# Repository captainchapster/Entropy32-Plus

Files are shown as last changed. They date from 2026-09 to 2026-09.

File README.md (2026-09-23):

# Entropy32 Plus

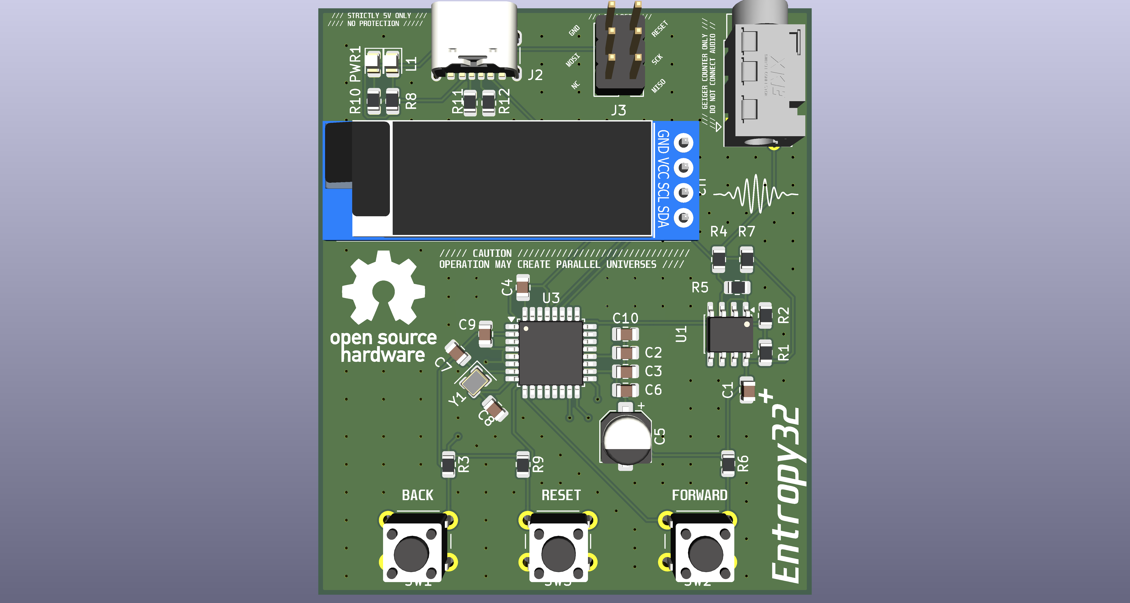
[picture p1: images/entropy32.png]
Assembled PCB


**Entropy32** (aka *The Universe Bifurcator*) is a dedicated Bitcoin seed phrase generator that uses radioactive decay as its entropy source. It's completely open source and designed to be simple, auditable, and buildable by anyone with readily available components.

## Why radioactive decay?

Pseudo-random number generators are deterministic — given the same seed, they always produce the same output. True randomness for something as consequential as a Bitcoin wallet's seed phrase should come from a physical process nobody can predict or manipulate. Radioactive decay is quantum-mechanically random: the timing of individual decay events is fundamentally unpredictable, making it an ideal entropy source for generating cryptographic secrets.

## How it works

1. A Geiger counter detects decay events from a radioactive source (or background) and outputs a pulse via a 3.5mm audio jack.
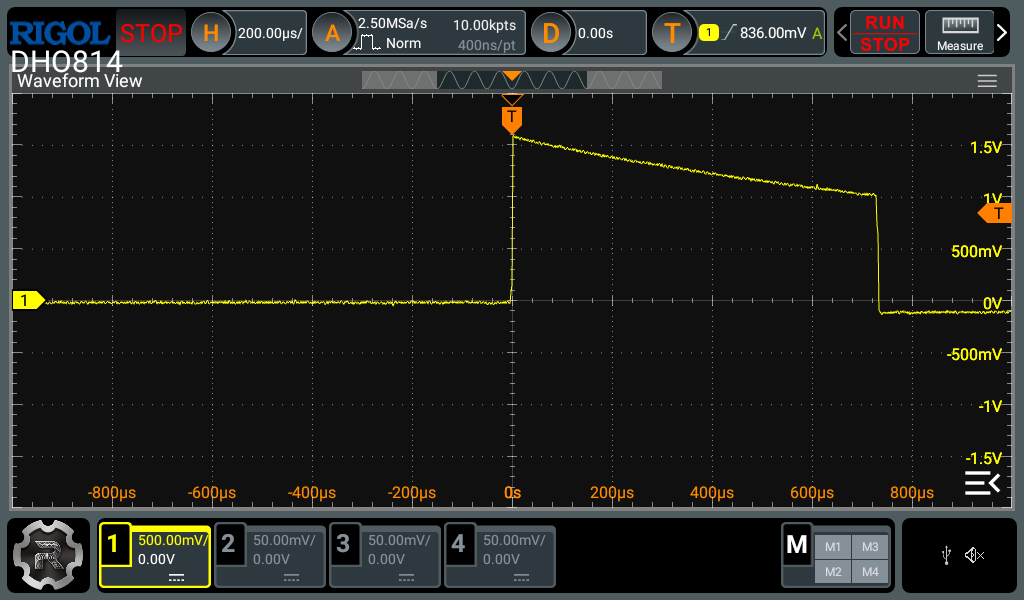
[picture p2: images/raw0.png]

2. An LM393 comparator IC then takes the 0-1.5V pulse and compares it to a bias of ~0.5V via a voltage divider such that if V>0.5V we get HIGH else LOW.
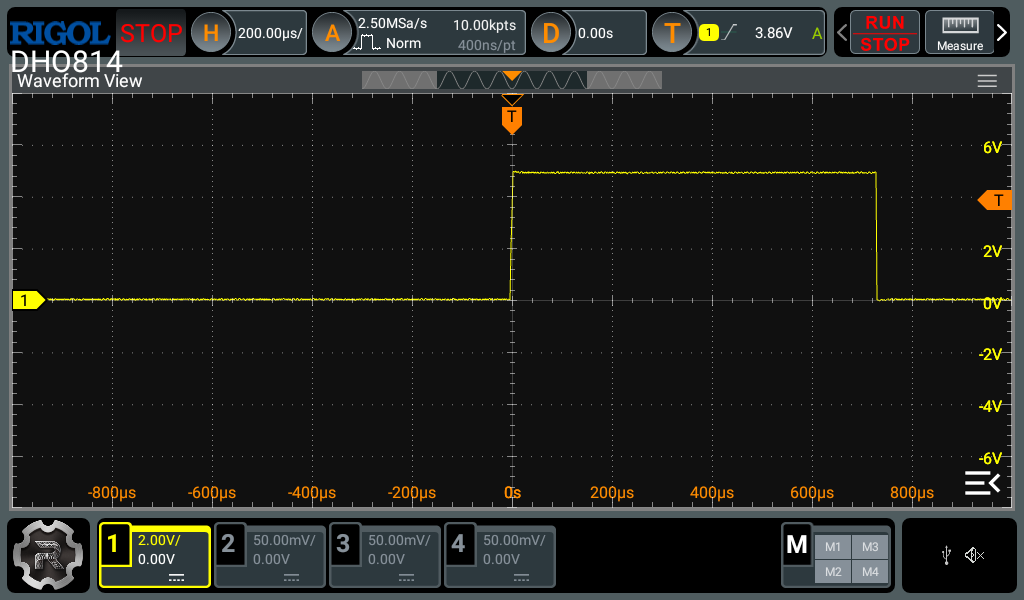
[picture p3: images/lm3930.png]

3. The timing between events is captured and compared in non-overlapping pairs (each inter-arrival time feeds exactly one comparison, so adjacent output bits never share an input interval). Each resulting bit passes two continuous NIST SP 800-90B health tests (Repetition Count Test and Adaptive Proportion Test) before it's fed through SHA-256 conditioning to whiten the raw entropy and remove any bias — if either test trips, the device halts rather than generating a seed from a degraded source.
4. The conditioned entropy is mapped to words from the standard BIP39 English wordlist.
5. A simple button-driven, state-machine UI walks you through generating and displaying your seed phrase — entirely offline, with no wireless connectivity, no persistent storage of the seed, and no software dependencies beyond the device itself.

## How long does it take to generate a seed?

The firmware always fills a 512-bit raw pool before conditioning — that's true whether you pick a 12-word or 24-word phrase, since the seed length only changes how many of the whitened bits get used afterward, not how much raw entropy gets collected. Because of the non-overlapping interval pairing described above, each output bit costs two Geiger pulses, so at a steady count rate the pool fills in roughly:

```
minutes ≈ 1024 / CPM
```

The device's collection screen shows live CPM and a running ETA using this same math, so you don't need to do it by hand. Actual CPM depends heavily on your specific tube, source activity, distance, and shielding — treat the table below as a rough guide, not a spec, and follow appropriate safety/legal practices for any check source you use:

| Source | Typical CPM | Time to fill the pool |
|---|---|---|
| Ambient background | ~15–25 CPM | ~40–70 min |
| Uranium glass ("vaseline glass") | ~50–100 CPM | ~10–20 min |
| Thoriated tungsten welding rod (2% ThO₂) | ~100–200 CPM | ~5–10 min |
| Am-241 foil (smoke detector ionization chamber) | ~300–800 CPM | ~1.3–3.5 min |
| Low-activity calibration/check source | ~1,000–3,000 CPM | ~20 sec–1 min |
| High-activity check source (close contact) | ~5,000–10,000+ CPM | ~6–12 sec |

## Hardware

- Custom PCB built around an [ATmega328P microcontroller](https://ww1.microchip.com/downloads/en/DeviceDoc/Atmel-7810-Automotive-Microcontrollers-ATmega328P_Datasheet.pdf), designed in [KiCad](https://www.kicad.org/)
- Geiger counter module as the entropy source (currently designed to take the 3.5mm output of the [GQ Electronics GMC-320S](https://www.gqelectronicsllc.com/comersus/store/comersus_viewItem.asp?idProduct=5787))
- [LM393 comparator IC](https://www.ti.com/product/LM393)
- Push-button interface for on-device operation
- Serveral common passives i.e. resistors, capacitors, and LEDs
- 16MHZ crystal oscillator
- 0.91" OLED display with I2C adaptor
- PJ320E 3.5mm audio jack
- USB-C receptacle 6 pin
- header pins

<p align="center">
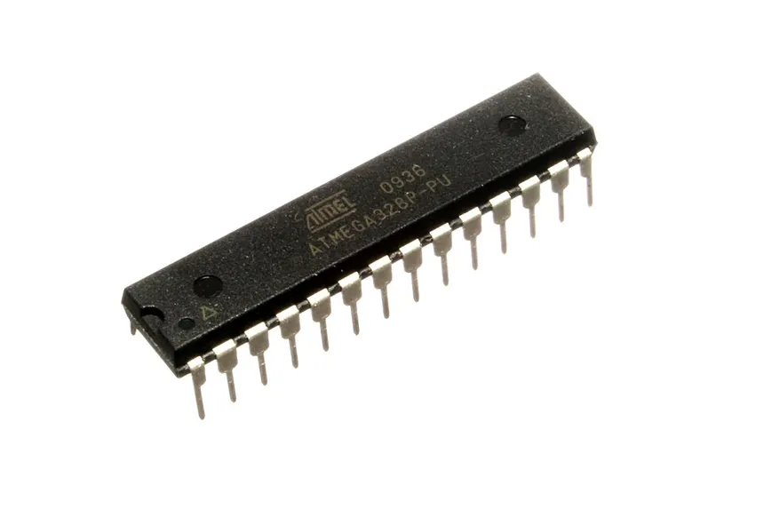
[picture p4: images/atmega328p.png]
ATmega328P
  
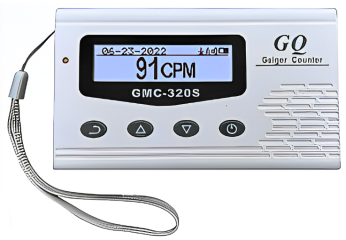
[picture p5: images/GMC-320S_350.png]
GMC-320S Geiger counter
  
</p>

## 3D printed case

I have included a custom designed basic case which you can 3d print to protect your device. The design works by allowing the board to slide on tracks into the case, once inserted all the way, a small prong prevents the board from sliding back out. If you plan to use this case be sure to hold the board down while unplugging the USB and/or the 3.5mm audio cable as this would otherwise put excessive strain on the prong to the point it may break off and fail. 

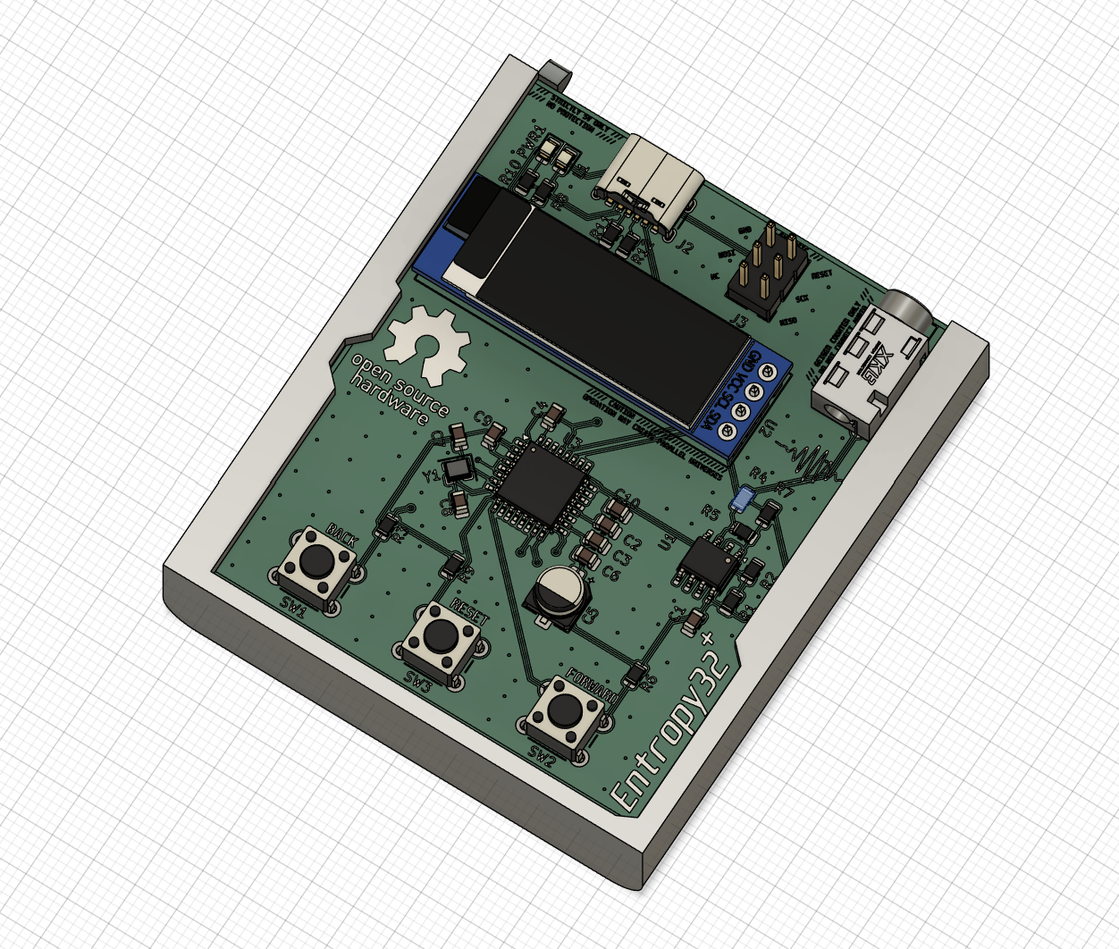
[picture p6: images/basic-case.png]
Basic Case


## Repository contents

| File | Purpose |
|---|---|
| `entropy32_plus.ino` | Main firmware — state machine, entropy capture, and UI logic |
| `sha256.h` / `sha256.cpp` | SHA-256 implementation used to condition raw entropy |
| `bip39_wordlist.h` | BIP39 English wordlist, compiled into firmware |
| `button.h` | Button input handling |
| `logo_bitmap.h` | Boot splash bitmap, compiled into firmware |
| `tools/english.txt` | Source BIP39 wordlist |
| `tools/generate_wordlist.py` | Script to regenerate `bip39_wordlist.h` from `english.txt` |
| `tools/generate_logo_bitmap.py` | Script to regenerate `logo_bitmap.h` from a rendered image |
| `KiCad/...` | Schematics, PCB and other files |
| `KiCad/production/...` | Fabrication data: bom, zipped fab files, and positions etc |
| `enclosures/...` | 3D print files for cases & enclosures |

## Building it yourself

Entropy32 schematic

The Arduino sketch (`entropy32_plus.ino`) and its accompanying `.h`/`.cpp` files must remain in the same top-level folder for the Arduino IDE to compile correctly — it doesn't recurse into subfolders for sketch code. Open `entropy32_plus.ino` in the Arduino IDE, verify your board settings for the ATmega328P, and flash as normal.

Use the KiCad files to tailor the board to your liking before fabrication or use the premade production files to order your board and/or pick and place from your preferred fabrication plant i.e. JLCPCB or PCB Way etc.

### Programming a bare ATmega328P

A freshly fabricated board has a blank ATmega328P — there's no bootloader on it and no USB-to-serial chip to flash it through, so the usual "select a port and hit upload" Arduino flow doesn't apply until it's been programmed once via the ICSP header exposed on the board.

1. **Wire up an ISP programmer.** Either a second Arduino running the `ArduinoISP` example sketch, or a dedicated programmer such as a USBasp, connected to the ICSP header. If using a USBasp, make sure it's set to 5V logic to match this board.
2. **Burn the bootloader.** In the Arduino IDE, select **Arduino Uno** or **Arduino Nano** as the board type (either is a stand-in for a bare ATmega328P at this stage), select your ISP programmer under Tools → Programmer, and run **Tools → Burn Bootloader**. This also sets the fuses for running off the board's 16MHz external crystal rather than the internal oscillator.
3. **Flash the firmware.** With the bootloader in place and the board running at 16MHz external clock, open `entropy32_plus.ino` and upload it via **Sketch → Upload Using Programmer** (still through the same ISP connection — the board has no onboard USB-serial chip for a normal serial upload).

## Flash footprint

Geiger pulse capture, the SP 800-90B runtime health tests, SHA-256 conditioning, the full BIP39 wordlist, the OLED driver, and the entire menu/boot UI all fit on the ATmega328P's 32KB of flash — with 486 bytes to spare:

```
Sketch uses 30234 bytes (98%) of program storage space. Maximum is 30720 bytes.
Global variables use 1061 bytes (51%) of dynamic memory, leaving 987 bytes for local variables. Maximum is 2048 bytes.
```

Breakdown of where it all goes, pulled from the compiled `.elf` with `avr-size`/`avr-nm`:

| Symbol | Bytes | What it is |
|---|---|---|
| `BIP39_WORDLIST_BLOB` | 13,117 | The official 2048-word BIP39 English wordlist |
| `main` (loop + inlined UI code) | 3,062 | State machine, screen drawing, menu logic |
| `SHA256::transform` | 2,278 | The SHA-256 compression function |
| `vfprintf` | 948 | Pulled in by `snprintf`, used for CPM/ETA/progress formatting |
| `u8x8_font_5x7_r` | 764 | Built-in OLED font glyph table |
| U8x8 / TwoWire internals | ~1,100 | I2C + SSD1306 driver plumbing |
| `LOGO_BITMAP` | 384 | Boot splash bitmap |
| `K` (SHA-256 round constants) | 256 | Fixed SHA-256 round constants |

The wordlist alone is 43% of the chip. Adafruit_GFX + Adafruit_SSD1306 don't fit alongside it — see the note in `entropy32_plus.ino` — which is why the firmware talks to the display through U8x8's text-only mode instead.

## Validation

The firmware runs the two minimal continuous health tests NIST SP 800-90B requires of a noise source at runtime — a Repetition Count Test and an Adaptive Proportion Test (see `runHealthChecks()` in `entropy32_plus.ino`) — which will halt the device rather than generate a seed if the raw source looks stuck or degraded. Runtime health tests are not the same as validating the source's entropy.

### Pilot entropy assessment

A 10-hour capture was logged with [Entropy32 Recorder](https://github.com/captainchapster/Entropy32-Recorder). The recorder is a separate board that timestamps the same post-LM393 D2 rising edges the firmware reads. It captured 10,000 edges (~17 CPM average) with zero buffer overruns or transport drops. The intervals were put through the firmware's exact bit derivation from this repository at `311c859`: 200 µs minimum interval, non-overlapping pairs and ties discarded. That produced 4,999 comparison bits (2,543 zeros, 2,456 ones). Those bits were assessed with NIST's [`ea_non_iid`](https://github.com/usnistgov/SP800-90B_EntropyAssessment) (v1.1.8):

| Estimator | Min-entropy (bits per bit) |
|---|---|
| Most Common Value | 0.924 |
| Collision | **0.738** |
| Markov | 0.956 |
| t-Tuple | 0.876 |
| LRS | 0.888 |
| MultiMCW prediction | 0.970 |
| Lag prediction | 0.915 |
| MultiMMC prediction | 0.919 |
| LZ78Y prediction | 0.922 |
| Compression | not run (too few samples) |

The assessed min-entropy is the lowest of these: **H ≈ 0.738 bits per comparison bit**, set by the collision estimator. At that rate, the 512-bit raw pool holds about 378 bits of min-entropy before SHA-256 conditioning. That is above the 256 bits a 24-word phrase needs.

Treat this as a pilot, not a validation:

- **4,999 samples is far short of the 1,000,000 the NIST tool is designed for.** The estimators use 99% upper confidence bounds, and those bounds are wide at this size, so the results are pessimistic. For example, the observed 50.9% / 49.1% split is within about 1.2 standard deviations of a fair coin. A full-length capture is still needed.
- It covers one device, one Geiger tube and one environment, and the source and setup details were not recorded. It says nothing about other builds.
- It is an entropy assessment, not NIST certification or formal validation.

The raw edges, derived bits, full tool output and SHA-256 checksums are all published in the [evidence directory](https://github.com/captainchapster/Entropy32-Recorder/tree/1d47487bc94c2b7c9baa2feec54d4443b60ba87c/entropy32_sp80090b_2026-09-22a), so the result can be reproduced end to end.

Please verify the entropy source you intend to use; otherwise, understand that you are using the device at your own risk.

## Disclaimer

This is a hobbyist/educational project. If you use it to generate a real Bitcoin seed phrase, understand the risks: verify the entropy quality yourself, review the code, and never trust a seed-generating device (this one included) with significant funds without independent auditing.

## Licenses

- For firmware/software, see [`MIT LICENSE`](./LICENSE).
- For hardware, see [`CERN-OHL-S v2 LICENSE`](./LICENSE-HARDWARE).

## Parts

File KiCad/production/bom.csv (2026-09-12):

Designator | Footprint | Quantity | Value | LCSC Part #
C1 | 0805 | 1 | 0.1uF
C10, C2, C9 | 0805 | 3 | 100nF
C3, C6 | 0805 | 2 | 1uF
C4 | 0805 | 1 | 100pF
C5 | CP_Elec_5x3 | 1 | 4.7uF
C7, C8 | 0805 | 2 | 10pF
J1 | Jack_3.5mm_PJ320E_Horizontal | 1 | AudioJack2
J2 | USB_C_Receptacle_GCT_USB4125-xx-x_6P_TopMnt_Horizontal | 1 | USB_C_Receptacle_PowerOnly_6P
J3 | PinHeader_2x03_P2.54mm_Vertical | 1 | ICSP
L1 | 0805 | 1 | Yellow
PWR1 | 0805 | 1 | Green
R1, R3, R6, R7, R9 | 0805 | 5 | 10k
R10 | 0805 | 1 | 2.2k
R11, R12 | 0805 | 2 | 5K1
R2, R4, R8 | 0805 | 3 | 1k
R5 | 0805 | 1 | 100k
SW1 | SW_PUSH_6mm | 1 | REV
SW2 | SW_PUSH_6mm | 1 | FWD
SW3 | SW_PUSH_6mm | 1 | RESET
U1 | SOIC-8_3.9x4.9mm_P1.27mm | 1 | LM393
U2 | ER_OLEDM0.91_1x-I2C | 1 | ER_OLEDM0.91_1x-I2C
U3 | TQFP-32_7x7mm_P0.8mm | 1 | ATmega328P-A
Y1 | Crystal_SMD_2520-4Pin_2.5x2.0mm | 1 | 16MHz

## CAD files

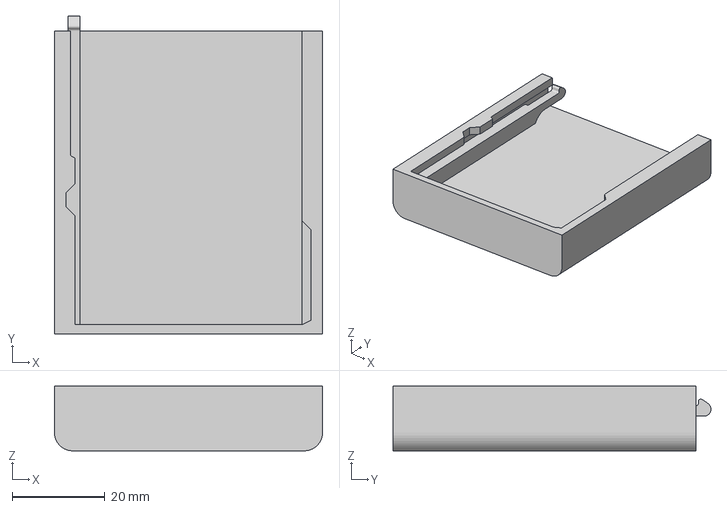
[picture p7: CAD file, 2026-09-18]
enclosures/Basic-case.3mf
58.0 x 68.7 x 14.0 mm

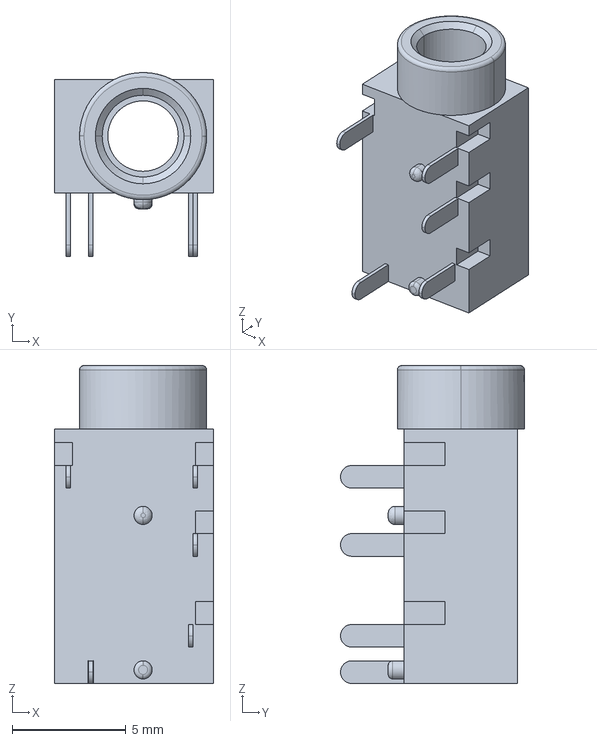
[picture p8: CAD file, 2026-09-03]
KiCad/3d_models/189198069-19-pj-320e/pj-320e.stp
7.00 x 8.10 x 14.0 mm

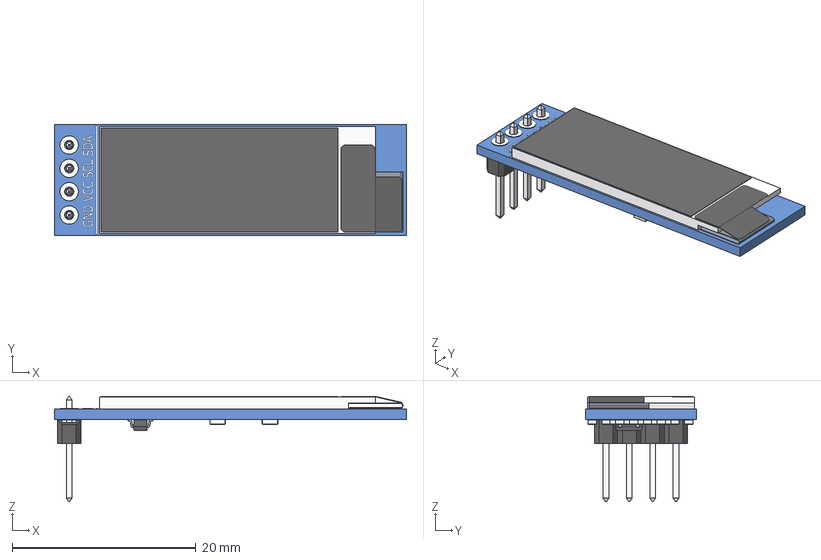
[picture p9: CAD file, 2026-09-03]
KiCad/3d_models/oled-0-91-128x32-1.snapshot.1/OLED_0.91_128x32.stp
38.3 x 12.1 x 11.5 mm
OLED_0.91_128x32
Pin Header 4 x 1 TH 2.54mm Pitch
RESC-0603 x 13
2SD0601A

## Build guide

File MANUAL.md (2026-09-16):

# Entropy32 Plus — User Manual

*"The Universe Bifurcator"*

<!-- IMAGE: hero shot — assembled device in its case, screen lit up on the
     collecting screen, Geiger counter cabled in beside it. This is the
     manual's cover image; make it the nicest photo you have. -->
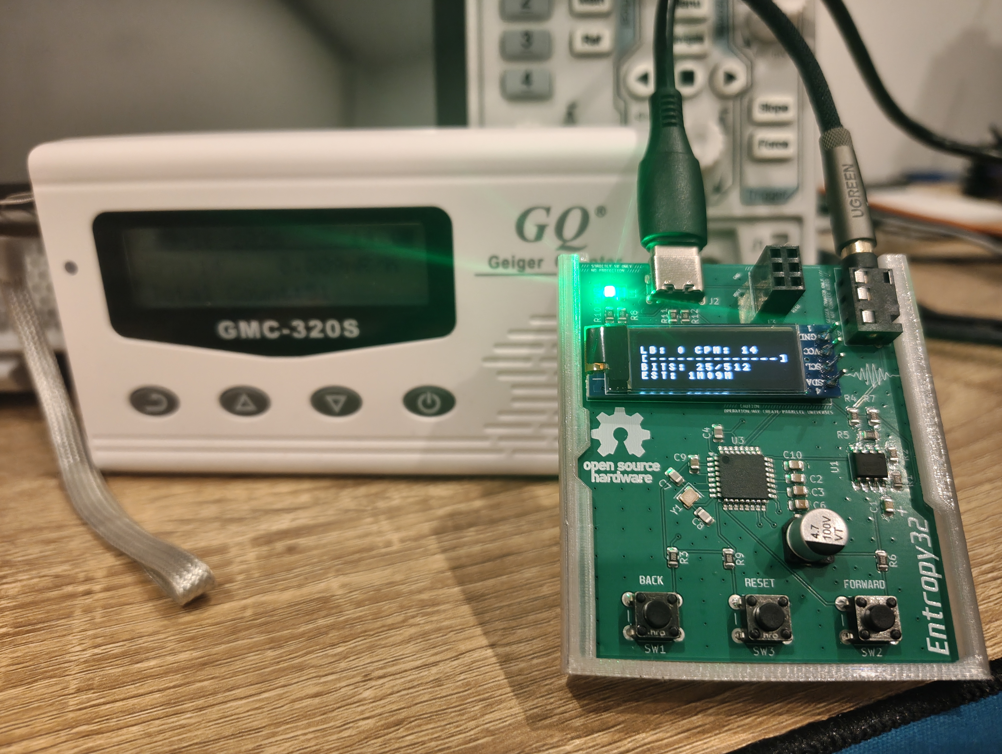
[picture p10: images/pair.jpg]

*Geiger counter not included!*

<details>
<summary>Why "The Universe Bifurcator"?</summary>

Every accepted bit this device produces comes from a single radioactive
decay event resolving one of two ways. Under the many-worlds
interpretation of quantum mechanics, that's the moment often described as
reality itself splitting into two branches — one per outcome. Calling the
device "The Universe Bifurcator" is equal parts joke and literal
description: your seed phrase isn't generated by a hardware trick
*pretending* to be random, it's built from actual forks in the universe's
wavefunction. Whether you take the physics interpretation seriously or
not, the entropy is real either way — see the README for how it's
captured and validated.

</details>

This manual covers day-to-day operation: what the buttons do, what each
screen means, and how to generate and record a BIP39 seed phrase. For
build instructions, schematics, and the cryptographic design, see the
[README](./README.md) instead.

---

## Table of contents

1. [Safety and disclaimer](#1-safety-and-disclaimer)
2. [What you need](#2-what-you-need)
3. [Device overview](#3-device-overview)
4. [Controls](#4-controls)
5. [Powering on and boot self-tests](#5-powering-on-and-boot-self-tests)
6. [Generating a seed phrase, step by step](#6-generating-a-seed-phrase-step-by-step)
7. [Screen reference](#7-screen-reference)
8. [Choosing an entropy source](#8-choosing-an-entropy-source)
9. [Troubleshooting](#9-troubleshooting)
10. [Caring for the device](#10-caring-for-the-device)
11. [Getting help](#11-getting-help)

---

## 1. Safety and disclaimer

<!-- IMAGE: none needed here — keep this section text-only so it reads
     like a warning label, not a photo spread. -->

**Radiation safety.** If you use a check source (uranium glass, thoriated
welding rod, a calibration source, etc.) rather than ambient background,
follow the safety and legal handling practices for that specific material
in your region. This device does not shield or contain a source for you —
that is entirely your responsibility.

**Seed security.** This is a hobbyist/educational project.

- Never trust a seed-generating device — this one included — with
  significant funds without independently auditing the hardware and
  firmware yourself.
- The device never stores, transmits, or displays your seed anywhere
  except its own screen, and it has no wireless connectivity — but *you*
  are still responsible for how you record and store it afterward.
- Don't photograph your seed phrase, type it into a computer or phone, or
  say it aloud near a smart speaker. Write it on paper (or stamp it in
  metal) and store that physically.
- If either on-device health check fails during generation, the device
  halts on purpose rather than producing a seed. See
  [Troubleshooting](#9-troubleshooting) — do not override this or
  retry until you understand why it tripped.

## 2. What you need

- The Entropy32 Plus device, assembled and flashed
- A Geiger counter with a 3.5mm pulse output (this device is designed
  around the GQ Electronics GMC-320S)
- A USB-C cable for power
- An entropy source: ambient background radiation works, or a check
  source if you want faster generation (see
  [Choosing an entropy source](#8-choosing-an-entropy-source))
- Something to record your seed phrase on — paper or a metal seed
  backup plate, kept offline

<!-- IMAGE: everything above laid out on a table, unboxing/kit-contents
     style. -->
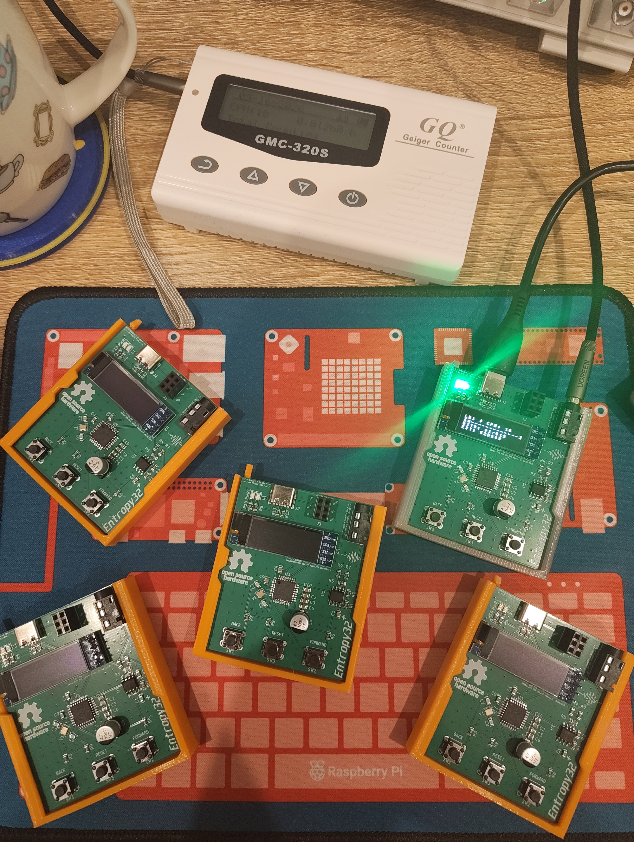
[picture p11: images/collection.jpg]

*Collect them all!*

## 3. Device overview

<!-- IMAGE: front of the device, in its case, with callout labels for:
     - OLED display
     - BACK button
     - FWD button
     Use arrows/numbers overlaid on the photo (a tool like Keynote,
     Figma, or even annotate on your phone works fine). -->
<p align="center">
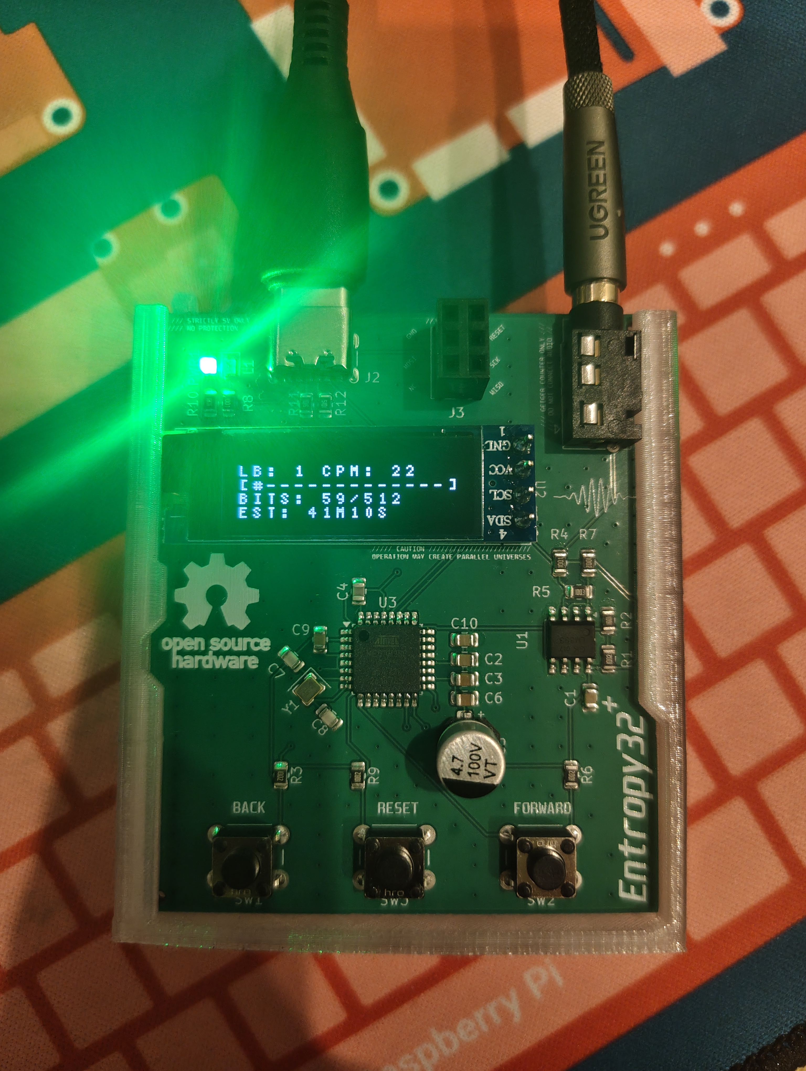
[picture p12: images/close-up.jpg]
  
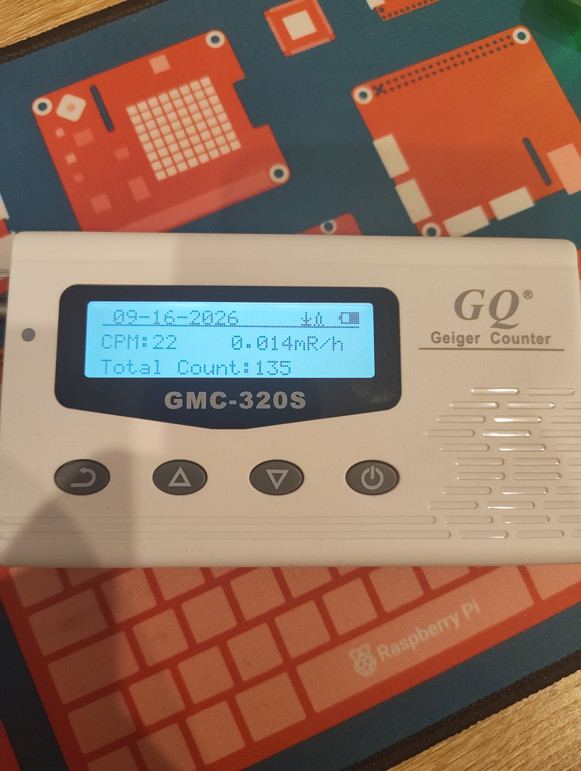
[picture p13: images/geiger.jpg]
  
  <br>
  <i>The CPM figure on the Geiger counter should agree with Entropy32 Plus</i>
</p>

<!-- IMAGE: side/back of the device with callouts for:
     - 3.5mm jack (Geiger counter input)
     - USB-C port (power) -->

| Callout | Part | Purpose |
|---|---|---|
| 1 | 0.91" OLED display | Shows collection progress, menus, and your seed phrase |
| 2 | BACK button | Navigate back / toggle menu options |
| 3 | FWD button | Navigate forward / toggle menu options |
| 4 | 3.5mm jack | Connects to your Geiger counter's pulse output |
| 5 | USB-C port | Power only |

## 4. Controls

The entire device is operated with two buttons. There is no text entry
and nothing to configure beyond seed length.

| Action | What it does |
|---|---|
| Press **BACK** alone | Go back / previous page / decrease-toggle |
| Press **FWD** alone | Go forward / next page / increase-toggle |
| Press **BACK + FWD together** | **Select / confirm** |

<!-- IMAGE: close-up of a hand pressing both buttons at once, to make the
     "combo = select" gesture unambiguous. -->

Hold both buttons together for a moment — the device waits briefly to
distinguish "two single presses" from "one combo press," so a firm,
simultaneous press works best.

## 5. Powering on and boot self-tests

Connect your Geiger counter's 3.5mm output to the device, then plug in
the USB-C cable to power it on. On every boot, the device automatically
runs a short sequence of self-tests before it will collect any entropy:

<!-- IMAGE: photo sequence (2-4 shots) of the boot screens in order:
     logo splash -> "BOOTING..." -> "TESTING SHA-256" -> "PASS <hash>"
     -> "CHECK WORDLIST" -> "PASS" -> collecting screen. -->
<p align="center">
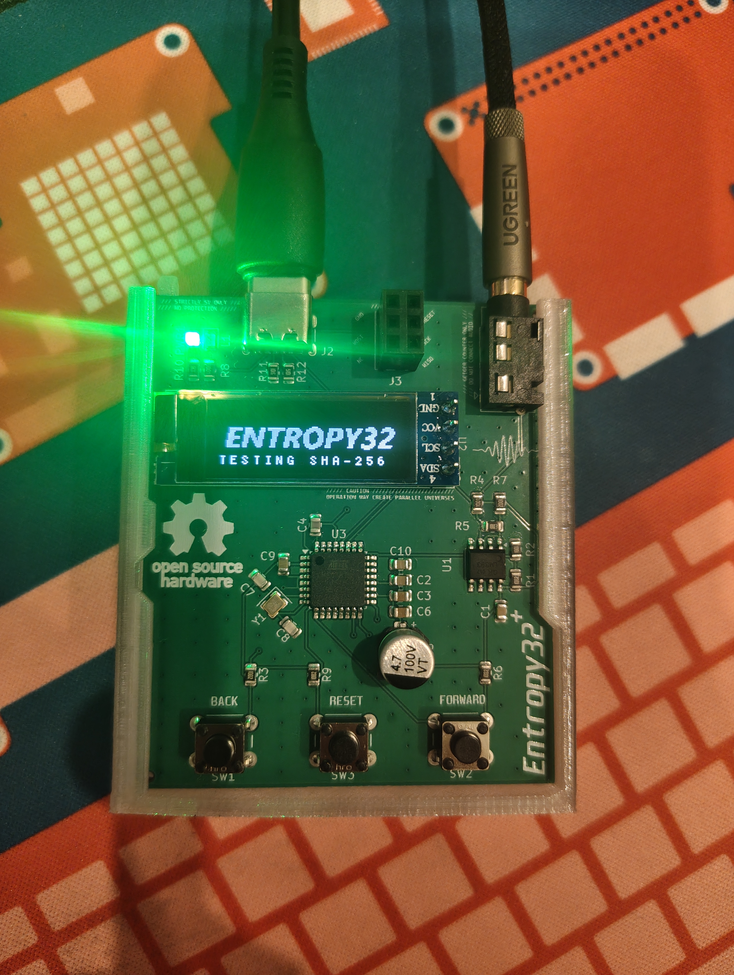
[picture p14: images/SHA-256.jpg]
  
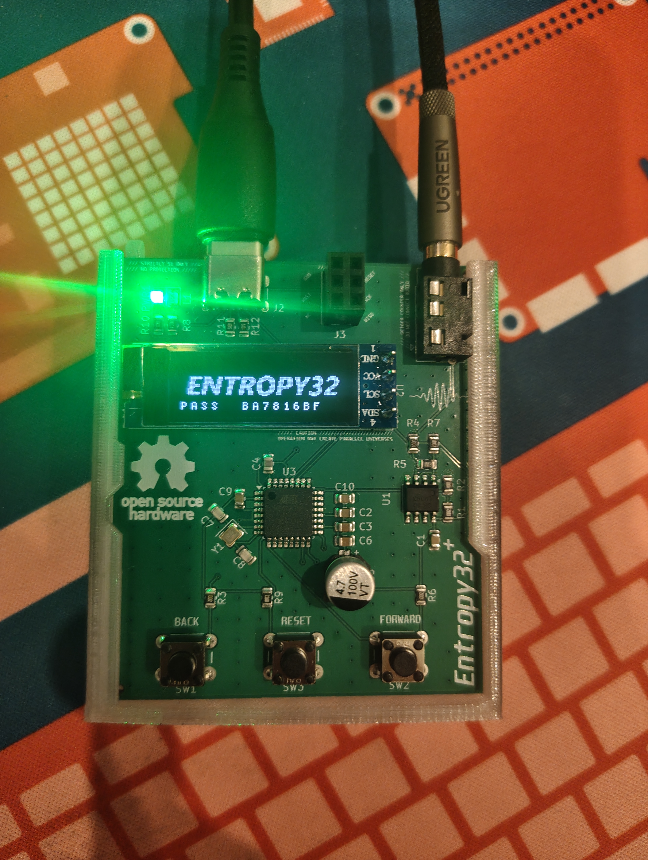
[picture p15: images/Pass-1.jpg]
  
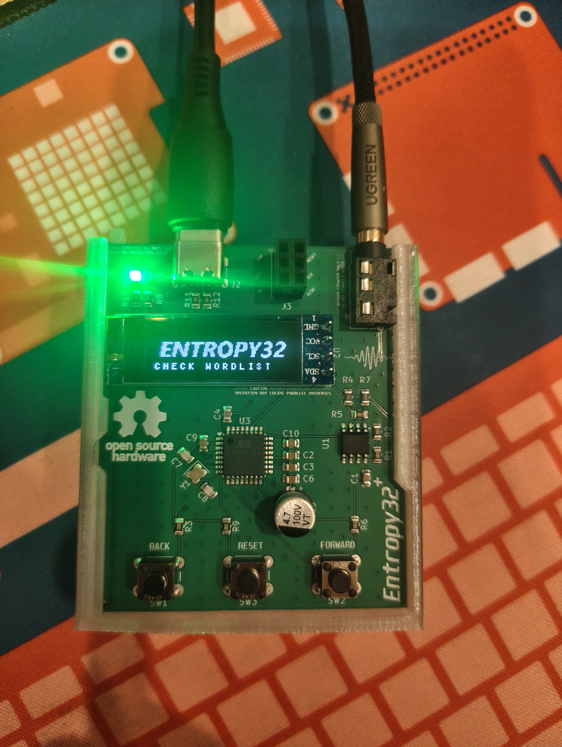
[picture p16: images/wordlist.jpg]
  
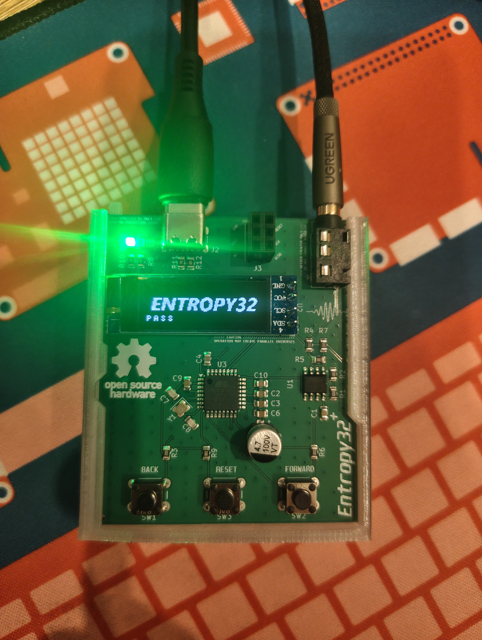
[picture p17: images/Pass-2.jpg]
  
  <br>
  <i>Boot sequence showing health checks passing</i>
</p>

1. **Logo splash** — the boot logo appears briefly.
2. **SHA-256 self-test** — the device hashes a known test string and
   checks the result against the correct answer, confirming its own
   cryptographic conditioning hasn't been broken by a bad build or
   corrupted flash. You'll briefly see `PASS` plus the first few bytes
   of the hash as a visual fingerprint.
3. **Wordlist check** — confirms the built-in BIP39 wordlist is intact.
4. The device moves into the **collecting** screen and begins listening
   for pulses.

If either test fails, the screen shows `FAIL - HALTED` or
`WORDLIST ERROR!` and the device stops responding to input entirely.
See [Troubleshooting](#9-troubleshooting).

## 6. Generating a seed phrase, step by step

### Step 1 — Collect entropy

<!-- IMAGE: the collecting screen, ideally with a Geiger counter visible
     next to it clicking away. A short video/GIF works even better if
     your README rendering target supports it. -->
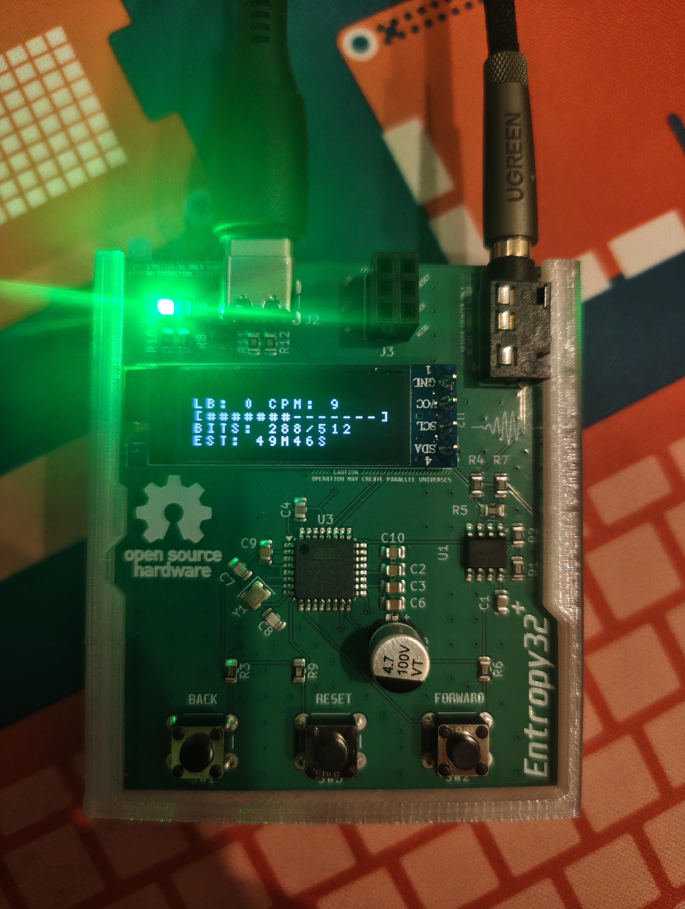
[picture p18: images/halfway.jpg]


Once booted, the device shows a live collection screen and starts
converting Geiger pulses into raw entropy bits automatically — there's
nothing to press here. Just wait. The screen shows your live pulse rate
and a progress bar; see [Screen reference](#7-screen-reference) for what
each field means. This can take anywhere from under a minute (strong
check source) to over an hour (ambient background) — the on-screen `EST`
field re-estimates the remaining time as data comes in.

### Step 2 — Choose seed length

<!-- IMAGE: the "SEED LENGTH: 12" / "SEED LENGTH: 24" menu screen. -->
<p align="center">
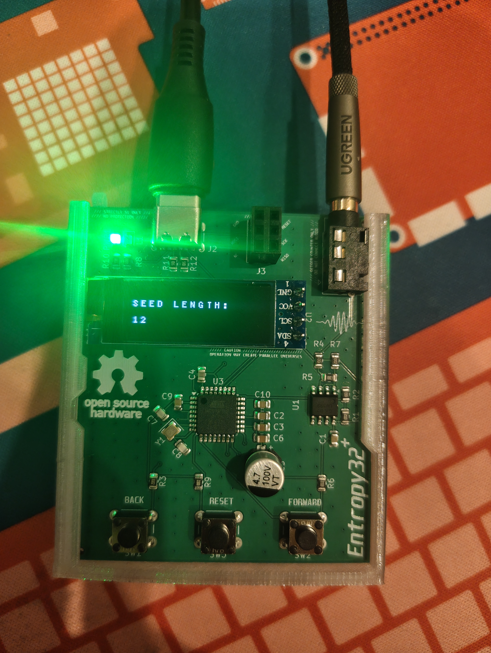
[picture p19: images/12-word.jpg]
  
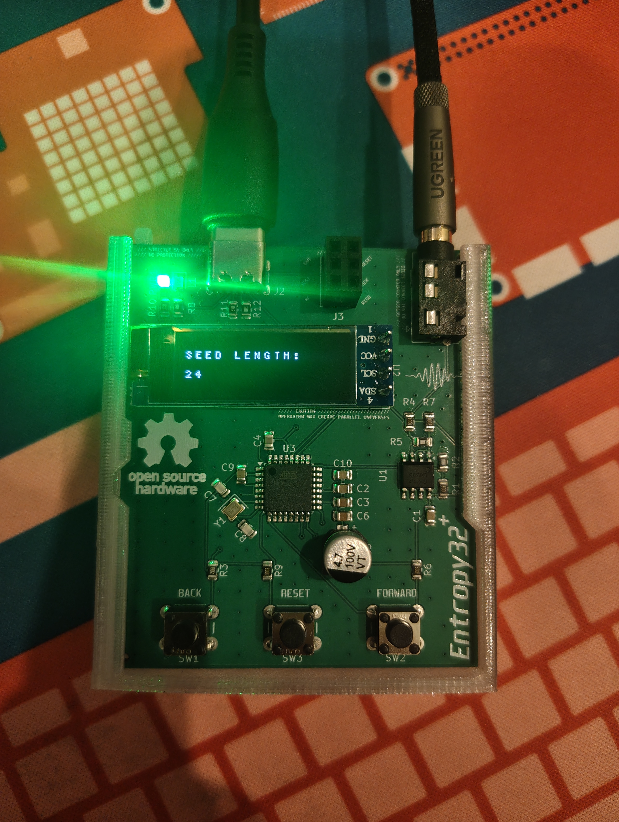
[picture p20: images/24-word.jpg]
  
  <br>
  <i>Seed phrase selection menu, user can elect a 12 or 24 word phrase</i>
</p>

Once the pool fills, the device automatically shows a menu:

```
SEED LENGTH:
12
```

Press **BACK** or **FWD** to toggle between `12` and `24` words, then
press **BACK + FWD together** to confirm your choice and generate the
phrase.

### Step 3 — Read your seed phrase

<!-- IMAGE: a word screen, e.g. showing words 01-04, with a hand writing
     the words onto paper alongside it. -->
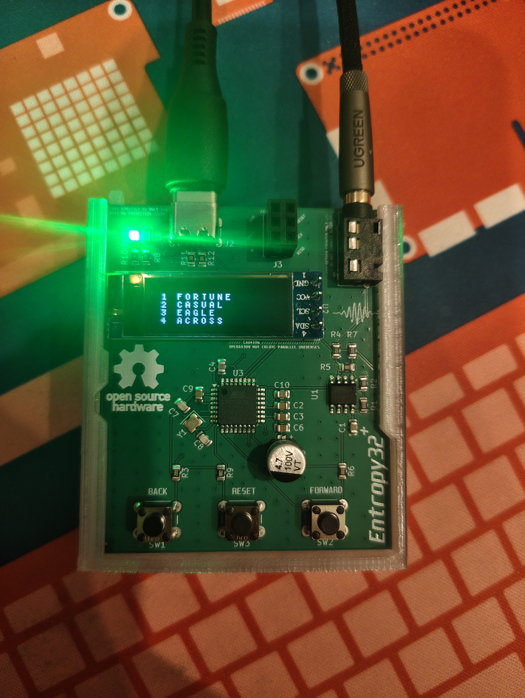
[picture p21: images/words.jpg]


The phrase is shown four words per screen, each numbered by its position
(e.g. `01 ABANDON`). Write each word down, in order, exactly as shown.

- Press **FWD** to go to the next page of words.
- Press **BACK** to go to the previous page (to double check what you
  wrote).
- A 12-word phrase is 3 pages; a 24-word phrase is 6 pages.

Take your time here — there's no timeout, and going back to re-check a
page does not regenerate or change anything.

### Step 4 — Finish and wipe

<!-- IMAGE: the "SEED COMPLETE." screen. -->
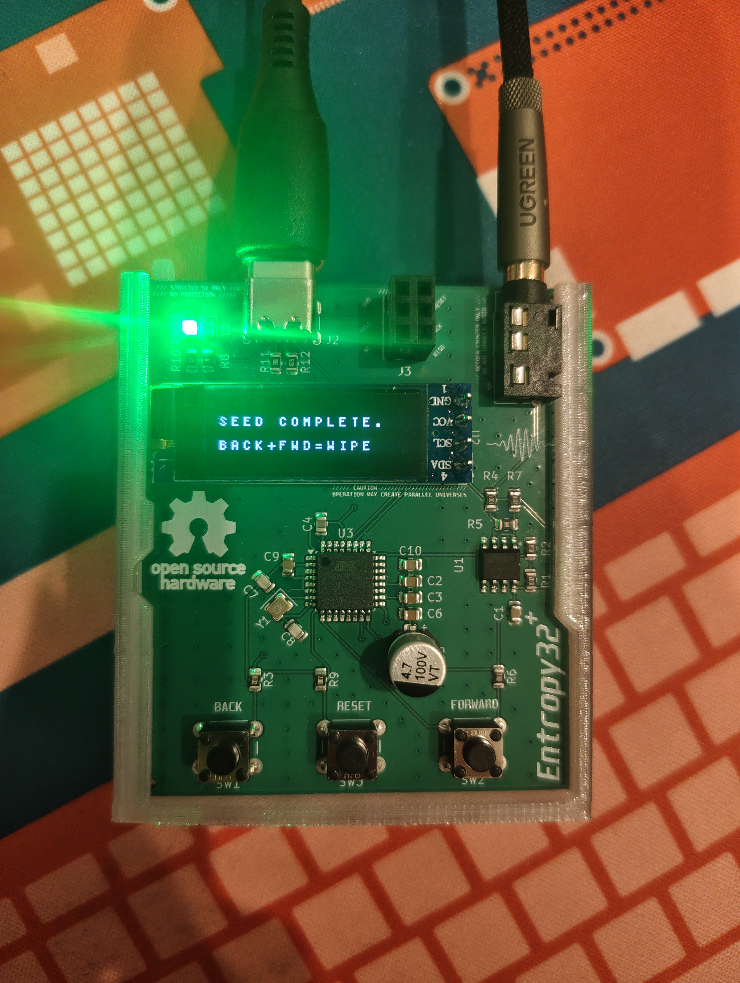
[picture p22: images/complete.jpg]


After the last page, the device shows:

```
SEED COMPLETE.
BACK+FWD=WIPE
```

From here:

- Press **BACK** to return to the word screens and review the phrase
  again.
- Press **BACK + FWD together** to move to the wipe confirmation screen.

<!-- IMAGE: the "WIPE SEED NOW?" confirmation screen. -->
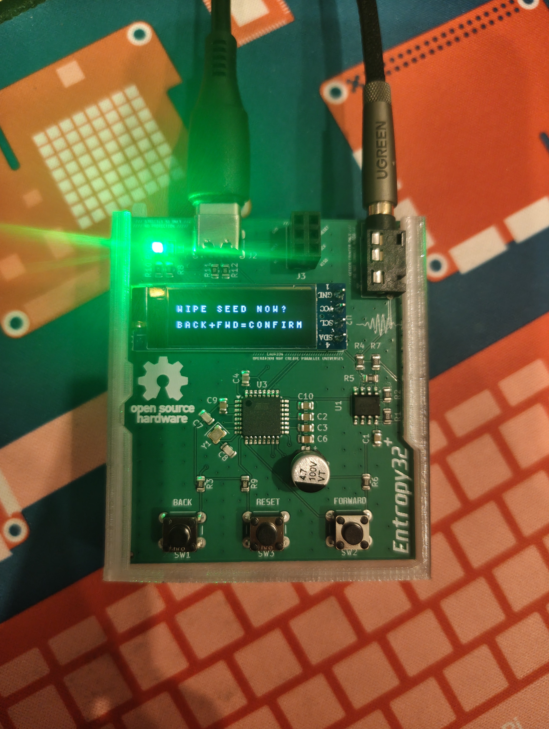
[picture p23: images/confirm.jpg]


```
WIPE SEED NOW?
BACK+FWD=CONFIRM
```

- Press **BACK + FWD together** again to confirm. The device erases the
  seed from memory and immediately restarts entropy collection for a
  fresh phrase.
- Press **BACK** or **FWD** alone to cancel and return to the completed
  seed screen instead.

**Do not walk away with a generated seed still on screen and unwiped** —
treat the wipe step as part of finishing the job, not optional cleanup.

## 7. Screen reference

### Collecting screen

```
LB: 1 CPM: 42.3K
[#######-------]
BITS: 312/512
EST: 2M15S
```

| Field | Meaning |
|---|---|
| `LB` | Value of the most recently accepted raw bit (`0` or `1`) — a quick liveness check that the source is actually producing data |
| `CPM` | Counts per minute from your Geiger counter, averaged over a rolling 60-second window - this should always match your Geiger counter's own CPM reading except during the first minute of operation |
| Progress bar | Fraction of the raw 512-bit entropy pool collected so far |
| `BITS` | Raw bits collected / 512 needed |
| `EST` | Estimated time remaining, based on current CPM |

### Menu screen

Shows the currently selected seed length (`12` or `24`). Toggle with
either button; confirm with the combo press.

### Word screens

Up to 4 words per screen, each prefixed with its 1-based position in the
phrase. Words are shown in uppercase for legibility on the small screen —
this is a display choice only; write them down however you like, case
doesn't matter for BIP39.

### Done / wipe screens

Text-only confirmation prompts — see [Step 4](#step-4--finish-and-wipe)
above for exactly what each button does on these screens.

## 8. Choosing an entropy source

The device works with any Geiger counter pulse source, but how fast it
fills its entropy pool depends entirely on your counts-per-minute (CPM).
Rough guide (see the README for the underlying math):

| Source | Typical CPM | Time to fill the pool |
|---|---|---|
| Ambient background | ~15–25 CPM | ~40–70 min |
| Uranium glass ("vaseline glass") | ~50–100 CPM | ~10–20 min |
| Thoriated tungsten welding rod (2% ThO₂) | ~100–200 CPM | ~5–10 min |
| Am-241 foil (smoke detector ionization chamber) | ~300–800 CPM | ~1.3–3.5 min |
| Low-activity calibration/check source | ~1,000–3,000 CPM | ~20 sec–1 min |
| High-activity check source (close contact) | ~5,000–10,000+ CPM | ~6–12 sec |

<!-- IMAGE: a couple of example sources next to the Geiger tube — e.g. a
     piece of uranium glass or a welding rod held near the counter — if
     you want to show, not just tell. Follow appropriate safety/legal
     practices for whatever source you photograph. -->

Actual CPM depends heavily on your specific tube, source activity,
distance, and shielding — treat the table as a rough guide, not a spec.

## 9. Troubleshooting

| Symptom | What it means | What to do |
|---|---|---|
| `FAIL - HALTED` at boot | SHA-256 self-test failed — the firmware build is likely corrupted | Re-flash the firmware; power cycle |
| `WORDLIST ERROR!` at boot | The compiled BIP39 wordlist has a corrupted/oversized entry | Regenerate `bip39_wordlist.h` from `tools/generate_wordlist.py` and re-flash |
| Screen never lights up | OLED not detected on the I2C bus | Check the display's I2C wiring/address; the device halts silently rather than running blind if it can't confirm the display |
| `HEALTH TEST FAIL` during collection | The entropy source looked stuck or statistically abnormal (NIST SP 800-90B runtime checks tripped) | Power cycle and try again; check your Geiger counter connection and source placement. Do not treat a health-test halt as a nuisance to bypass — it exists to stop a degraded source from silently producing a weak seed |
| `CPM` reads 0 / `EST` reads `--` | No pulses are being received | Check the 3.5mm cable connection and that your Geiger counter is actually powered on and detecting counts |
| Progress bar stuck | Very low count rate (ambient background can genuinely take an hour+) | Wait, or switch to a stronger source — see [Choosing an entropy source](#8-choosing-an-entropy-source) |
| A button press does nothing | You may be mid-combo-detection window, or the device already halted on a self-test/health-test failure | Press firmly and release; if the screen shows a halt message, this is expected — power cycle |

Any halt state (`FAIL - HALTED`, `WORDLIST ERROR!`, `HEALTH TEST FAIL`)
requires a power cycle to recover — this is intentional, not a bug.

## 10. Caring for the device

<!-- IMAGE: hand holding the case steady while unplugging the USB-C or
     3.5mm cable, demonstrating the warning below. -->

If you're using the included 3D-printed case: hold the board down while
unplugging the USB-C or 3.5mm cable. The case's retention prong resists
the board sliding out, and repeated unplugging without supporting the
board can eventually snap it.

Beyond that, treat it like any small electronics project — avoid static
discharge into the exposed header pins, and don't leave it connected to
an active source indefinitely when not in use.

## 11. Getting help

This is an open-source hobbyist project — see the
[README](./README.md) for hardware design files, firmware source, and
the full technical writeup of how entropy is captured and conditioned.

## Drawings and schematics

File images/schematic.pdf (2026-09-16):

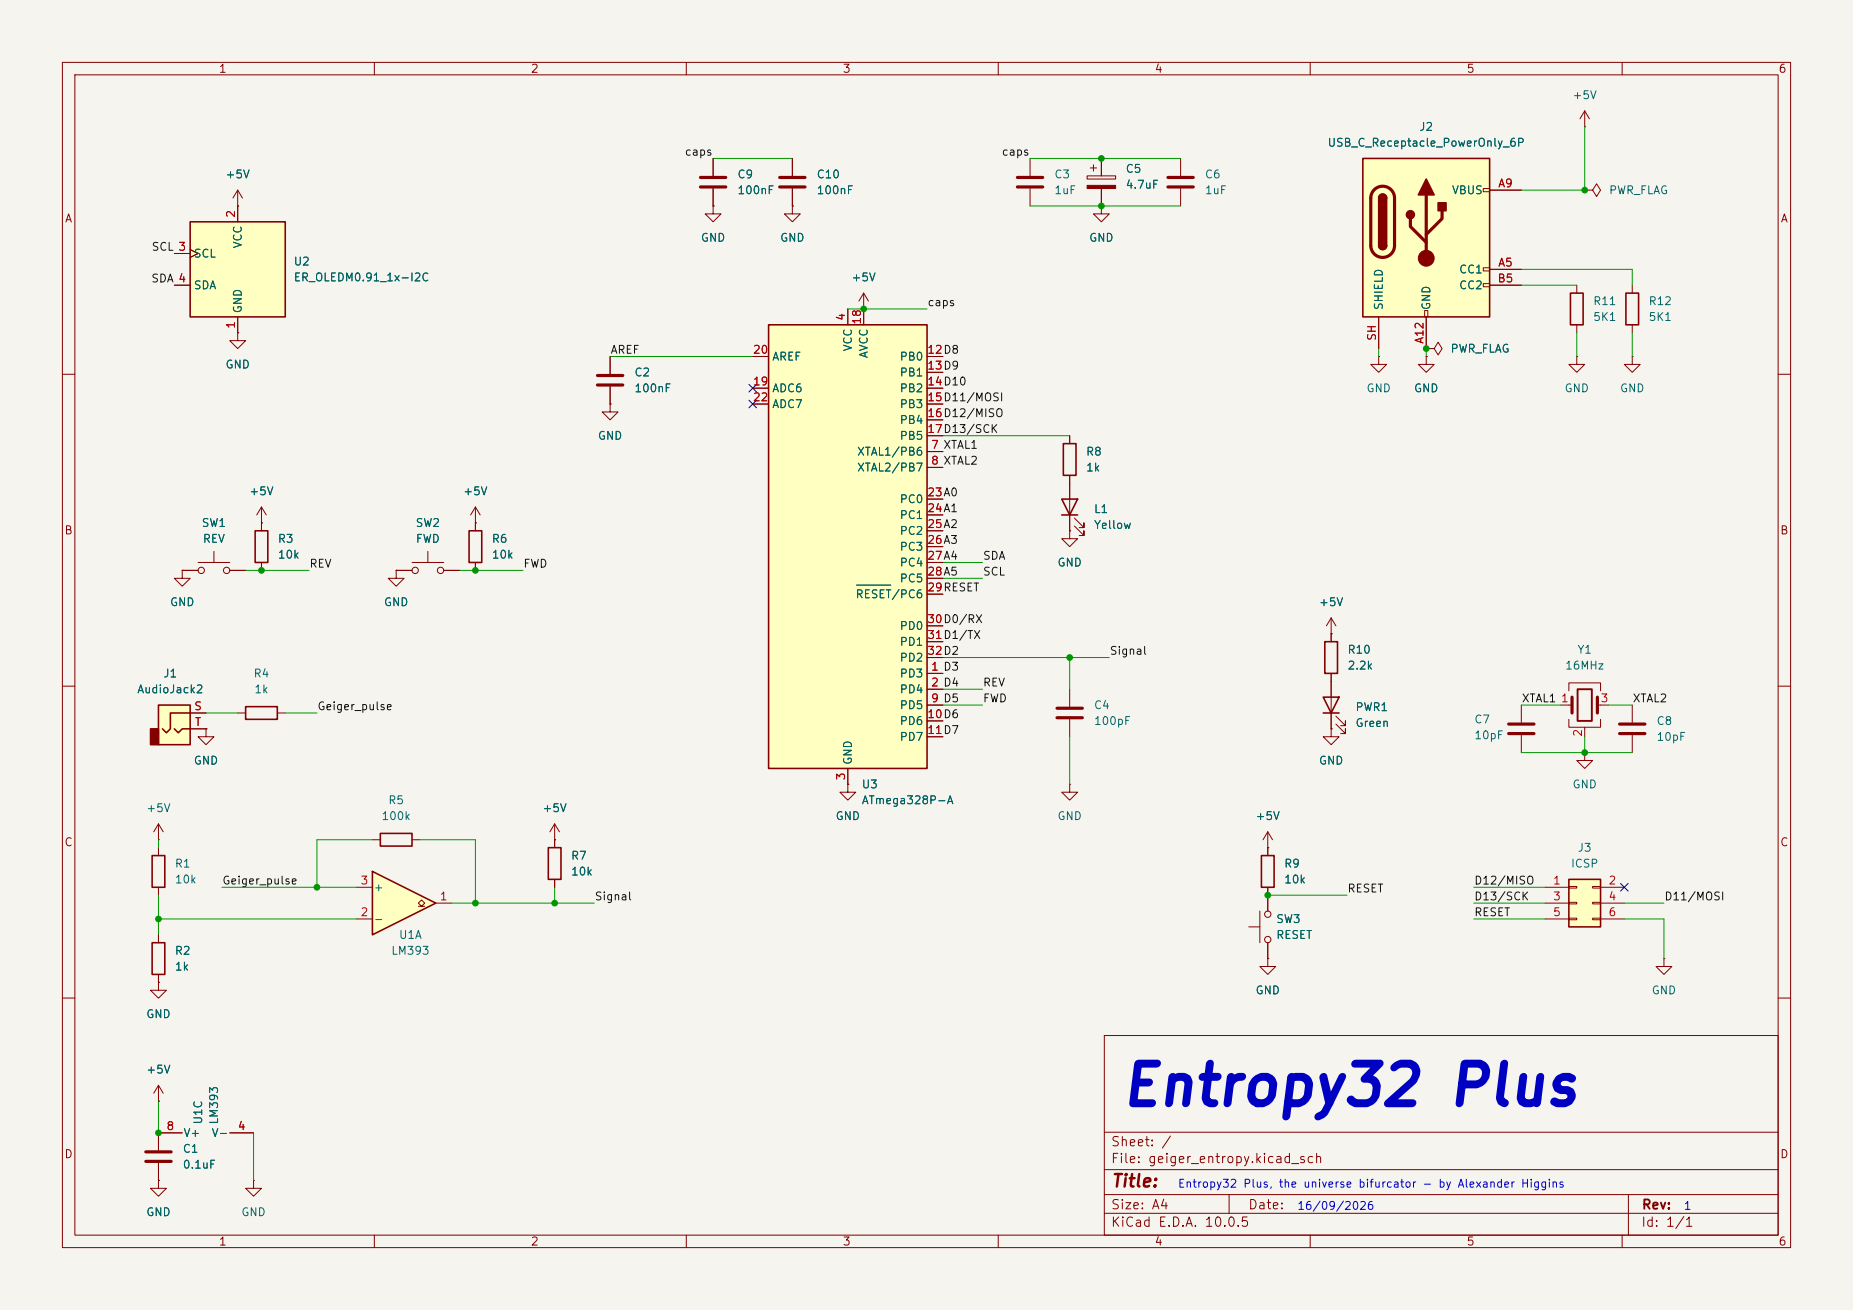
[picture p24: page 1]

Entropy32 Plus, the universe bifurcator - by Alexander Higgins GND

Size: A4 | Rev:
KiCad E.D.A. 10.0.5 | Id: 1/1

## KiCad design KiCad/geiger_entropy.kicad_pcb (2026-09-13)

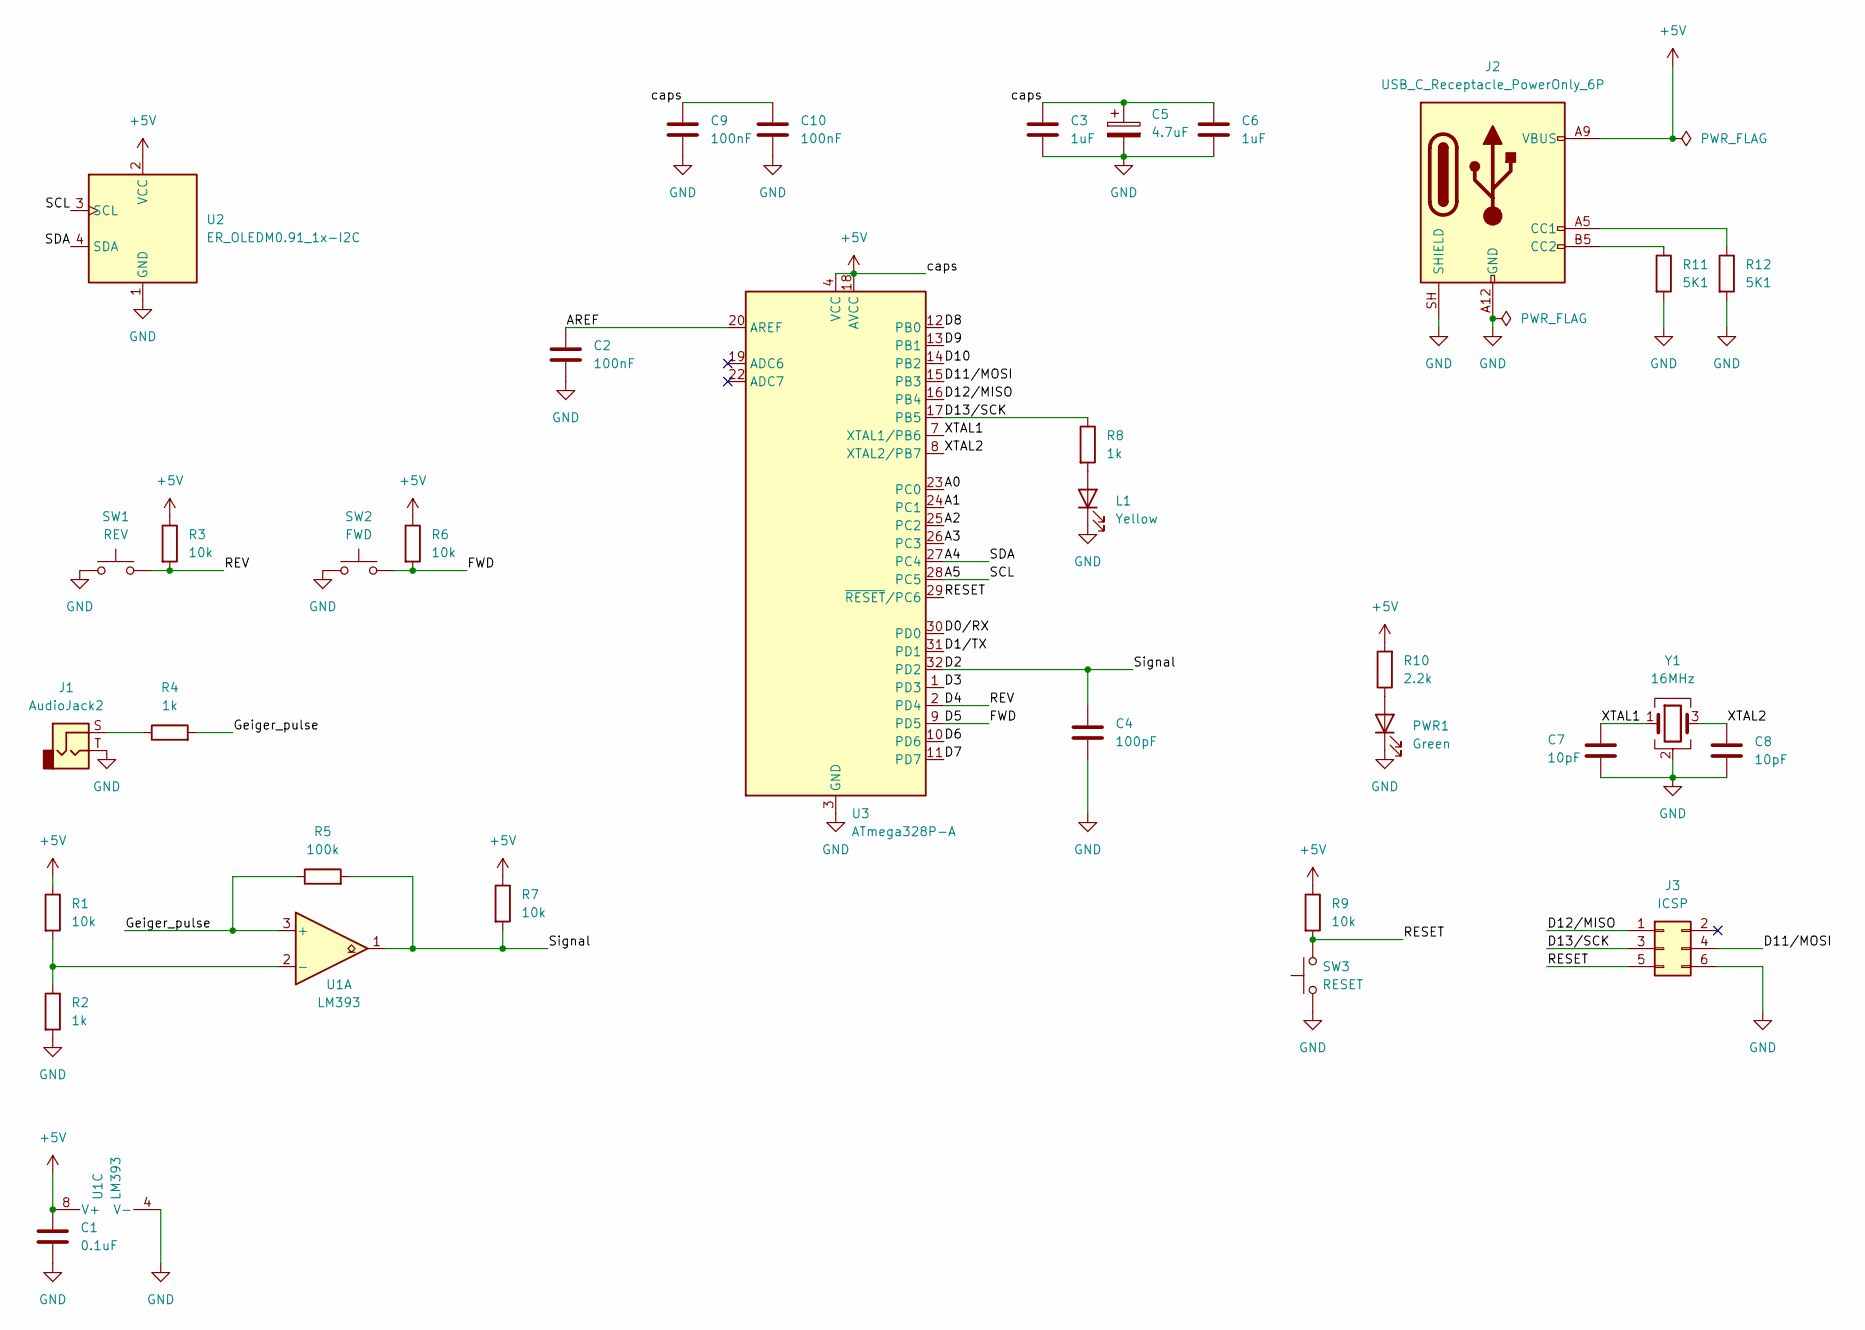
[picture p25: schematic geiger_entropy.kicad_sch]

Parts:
C1: 0.1uF; C_0805_2012Metric
C2, C9, C10: 100nF; C_0805_2012Metric
C3, C6: 1uF; C_0805_2012Metric
C4: 100pF; C_0805_2012Metric
C5: 4.7uF; CP_Elec_5x3
C7, C8: 10pF; C_0805_2012Metric
J1: AudioJack2; Jack_3.5mm_PJ320E_Horizontal
J2: USB_C_Receptacle_PowerOnly_6P; USB_C_Receptacle_GCT_USB4125-xx-x_6P_TopMnt_Horizontal
J3: ICSP; PinHeader_2x03_P2.54mm_Vertical
L1: Yellow; LED_0805_2012Metric
PWR1: Green; LED_0805_2012Metric
R1, R3, R6, R7, R9: 10k; R_0805_2012Metric
R2, R4, R8: 1k; R_0805_2012Metric
R5: 100k; R_0805_2012Metric
R10: 2.2k; R_0805_2012Metric
R11, R12: 5K1; R_0805_2012Metric
SW1: REV; SW_PUSH_6mm
SW2: FWD; SW_PUSH_6mm
SW3: RESET; SW_PUSH_6mm
U1: LM393; SOIC-8_3.9x4.9mm_P1.27mm
U2: ER_OLEDM0.91_1x-I2C
U3: ATmega328P-A; TQFP-32_7x7mm_P0.8mm
Y1: 16MHz; Crystal_SMD_2520-4Pin_2.5x2.0mm

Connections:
+5V: C1.1, C3.1, C5.1, C6.1, C9.1, C10.1, J2.A9 (VBUS), J2.B9 (VBUS), R1.1, R3.1, R6.1, R7.1, R9.1, R10.2, U1.8 (V+), U2.2 (VCC), U3.4 (VCC), U3.6 (VCC), U3.18 (AVCC)
/A0: U3.23 (PC0)
/A1: U3.24 (PC1)
/A2: U3.25 (PC2)
/A3: U3.26 (PC3)
/A4: U2.4 (SDA), U3.27 (PC4)
/A5: U2.3 (SCL), U3.28 (PC5)
/AREF: C2.1, U3.20 (AREF)
/D0/RX: U3.30 (PD0)
/D1/TX: U3.31 (PD1)
/D2: C4.1, R5.2, R7.2, U1.1, U3.32 (PD2)
/D3: U3.1 (PD3)
/D4: R3.2, SW1.2, U3.2 (PD4)
/D5: R6.2, SW2.2, U3.9 (PD5)
/D6: U3.10 (PD6)
/D7: U3.11 (PD7)
/D8: U3.12 (PB0)
/D9: U3.13 (PB1)
/D10: U3.14 (PB2)
/D11/MOSI: J3.4, U3.15 (PB3)
/D12/MISO: J3.1, U3.16 (PB4)
/D13/SCK: J3.3, R8.1, U3.17 (PB5)
/Geiger_pulse: R4.2, R5.1, U1.3 (+)
/RESET: J3.5, R9.2, SW3.2, U3.29 (~RESET/PC6)
/XTAL1: C7.1, U3.7 (XTAL1/PB6), Y1.1
/XTAL2: C8.1, U3.8 (XTAL2/PB7), Y1.3
GND: C1.2, C2.2, C3.2, C4.2, C5.2, C6.2, C7.2, C8.2, C9.2, C10.2, J1.T, J2.A12 (GND), J2.B12 (GND), J2.SH (SHIELD), J3.6, L1.1 (K), PWR1.1 (K), R2.2, R11.2, R12.2, SW1.1, SW2.1, SW3.1, U1.4 (V-), U2.1 (GND), U3.3 (GND), U3.5 (GND), U3.21 (GND), Y1.2 (G), Y1.4 (G)
unnamed: J1.S, R4.1
unnamed: J2.A5 (CC1), R12.1
unnamed: J2.B5 (CC2), R11.1
unnamed: L1.2 (A), R8.2
unnamed: PWR1.2 (A), R10.1
unnamed: R1.2, R2.1, U1.2 (-)

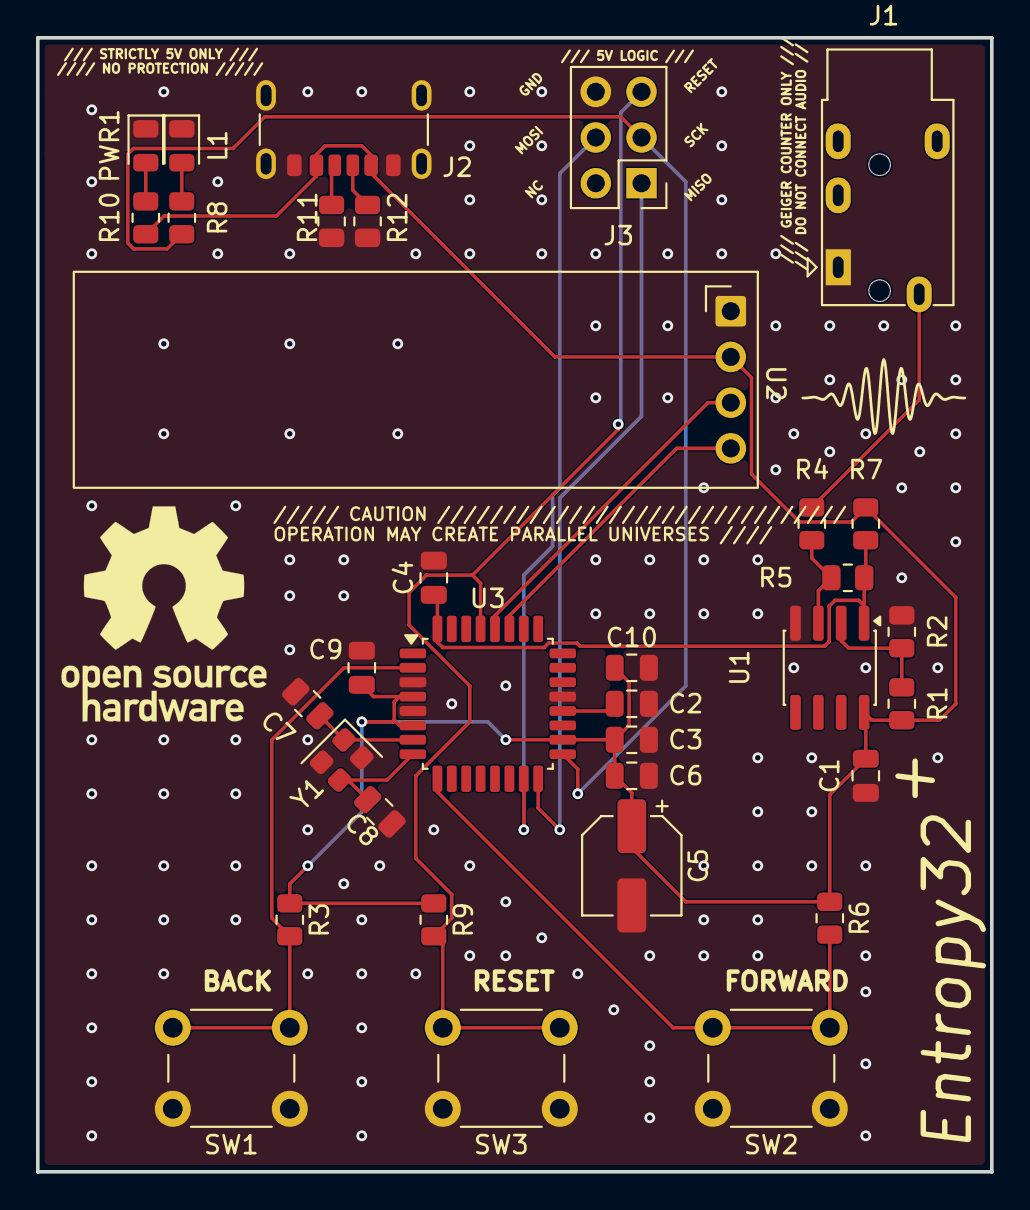
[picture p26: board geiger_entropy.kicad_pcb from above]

Board: 2 copper layers, 53.0 x 63.0 mm, 34 parts (0 on the bottom side), 21 nets.

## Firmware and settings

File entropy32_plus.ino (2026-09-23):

/*
 * Entropy32 Plus - "The Universe Bifurcator"
 * ---------------------------------------------------------
 * Geiger-pulse based TRNG -> BIP39 seed phrase generator
 *
 * Hardware:
 *   - ATmega328P
 *   - 0.91" 128x32 OLED (SSD1306) via I2C (SDA=A4, SCL=A5)
 *   - Processed Geiger pulses (post-LM393) on D2 (INT0)
 *   - Back button  -> D4 (active LOW, internal pull-up)
 *   - Forward button -> D5 (active LOW, internal pull-up)
 *
 * Entropy method:
 *   1. Capture inter-arrival time between successive Geiger pulses.
 *   2. Compare intervals in non-overlapping pairs (T1,T2) -> bit,
 *      (T3,T4) -> bit, (T5,T6) -> bit, etc:
 *        second longer  -> bit 1
 *        second shorter -> bit 0
 *        equal          -> pair discarded (extremely rare at microsecond
 *                           resolution)
 *      Each interval feeds exactly one comparison. An earlier revision
 *      compared every interval to the one before it (T2 vs T1, then T3
 *      vs T2, ...), which reuses each interval in two consecutive
 *      comparisons and correlates adjacent output bits even when the
 *      underlying intervals are IID. Non-overlapping pairing costs half
 *      the raw bit rate but removes that artifact.
 *   3. Run each comparison-bit through two continuous online health
 *      tests (NIST SP 800-90B 4.4.1/4.4.2 minimal tests, see
 *      runHealthChecks()) before it's added to the pool, and halt
 *      rather than generate a seed if either one trips.
 *   4. Collect a raw pool of comparison-bits (RAW_POOL_BITS).
 *   5. Whiten/condition the raw pool with SHA-256 to remove any
 *      residual structure (dead-time correlation, count-rate drift, etc).
 *   6. Follow the standard BIP39 process on the conditioned entropy:
 *      compute checksum = first ENT/32 bits of SHA256(entropy),
 *      append it, split into 11-bit chunks, map each chunk to a
 *      word in the official 2048-word list.
 *
 * IMPORTANT / CAVEAT:
 *   This is a hobbyist/prototype entropy source. Before trusting output
 *   from this device for a seed that will secure real funds:
 *     - Log raw inter-arrival times over a long run and evaluate them
 *       with the NIST SP 800-90B non-IID min-entropy estimators (not
 *       just SP 800-22 pass/fail randomness tests) to confirm the raw
 *       pool has genuinely enough min-entropy for what you're claiming.
 *     - Consider mixing this source with a second, independently-
 *       validated entropy source (e.g. your avalanche-noise Bifurcator)
 *       before finalizing a seed for anything holding real value.
 *     - Never transcribe a generated phrase for real funds directly off
 *       a device you haven't independently audited end-to-end.
 *
 * Required libraries:
 *   - U8g2 (olikraus) - only the U8x8 text-mode API is used. U8x8 talks
 *     directly to the display a character cell at a time with no RAM
 *     framebuffer and a compact built-in font, unlike Adafruit_GFX +
 *     Adafruit_SSD1306 (which pull in a full graphics stack - shape
 *     drawing, a 512-byte framebuffer, and unrelated SPI-TFT code paths
 *     the linker can't strip because of virtual dispatch). That combo
 *     alone doesn't fit in the ATmega328P's 32KB flash next to the rest
 *     of this sketch. Install "U8g2" via the Arduino IDE Library Manager.
 *
 * Required companion files (same sketch folder):
 *   - sha256.h / sha256.cpp   (included, self-contained, no dependency)
 *   - bip39_wordlist.h        (generate with generate_wordlist.py)
 */

#include <Wire.h>
#include <U8x8lib.h>
#include <ctype.h>
#include "sha256.h"
#include "bip39_wordlist.h"
#include "button.h"
#include "logo_bitmap.h"

// ---------------- Pin assignments ----------------
#define GEIGER_PIN 2   // INT0 - processed pulse edge from LM393
#define BACK_PIN   4
#define FWD_PIN    5

// ---------------- OLED ----------------
// 0.91" SSD1306 modules are almost always 128x32 pixels, giving a 16
// column x 4 row text grid with U8x8's 8px-wide font tiles. Common I2C
// addresses are 0x3C or 0x3D - run an I2C scanner sketch once if the
// display doesn't init, and adjust OLED_ADDR below.
#define OLED_ADDR    0x3C
#define OLED_COLS    16
#define OLED_ROWS    4

U8X8_SSD1306_128X32_UNIVISION_HW_I2C lcd(U8X8_PIN_NONE);

// ---------------- CPM tracking ----------------
#define CPM_WINDOW_SECONDS 60
volatile uint32_t totalPulseCount = 0; // all raw pulses seen by the ISR, unfiltered by MIN_INTERVAL_US

uint16_t cpmSecondBuckets[CPM_WINDOW_SECONDS] = {0};
uint8_t  cpmBucketIdx        = 0;
uint32_t cpmRollingSum       = 0;  // sum of the last <=60 one-second buckets
uint32_t cpmLastPulseSnapshot = 0;
unsigned long cpmLastTickMs  = 0;
uint8_t  cpmSecondsElapsed   = 0;  // caps at CPM_WINDOW_SECONDS; used to scale early readings

// ---------------- Entropy collection ----------------
#define RAW_POOL_BITS    512     // raw comparison-bits collected before offering the menu
#define MIN_INTERVAL_US  200     // reject intervals shorter than this (debounce/glitch guard)

volatile uint8_t  entropyPool[RAW_POOL_BITS / 8]; // bit-packed raw pool
volatile uint16_t poolBitIndex   = 0;
volatile unsigned long lastPulseMicros = 0;
// Non-overlapping pairing state: each interval feeds exactly one
// comparison, so the first interval of a pair is held here until the
// second arrives, then both are discarded (tie or not) before the next
// pair starts. This is what keeps adjacent output bits from sharing an
// input interval - see the "Entropy method" note at the top of this file.
volatile unsigned long firstInterval = 0;
volatile bool haveFirstInterval = false;

// ---------------- Entropy health tests ----------------
// The two continuous minimal health tests from NIST SP 800-90B 4.4.1
// (Repetition Count Test) and 4.4.2 (Adaptive Proportion Test), run on
// every raw comparison bit before it reaches entropyPool. They exist to
// catch a stuck/degraded noise source (dead sensor, jammed comparator,
// stuck-high/low input) at runtime, not to certify entropy quality - that
// still requires the offline SP 800-90B estimation described under
// Validation in the README.
//
// Cutoffs assume a conservative claimed per-bit min-entropy H = 1 (i.e.
// "does this still look like a fair coin flip") and a false-positive
// probability alpha = 2^-20, the NIST-recommended default:
//   RCT cutoff  C = ceil(1 + (-log2(alpha) / H)) = ceil(1 + 20/1) = 21
//   APT cutoff, window W = 512: using the normal approximation to the
//   binomial tail (mean = W/2 = 256, sigma = sqrt(W/4) = 11.31, z for
//   alpha = 2^-20 is ~6.36) gives cutoff ~= 256 + 6.36*11.31 = 328. This
//   is a coarse stand-in for the exact tail sum in the spec - cheap
//   enough for the AVR and conservative enough to still catch a
//   genuinely stuck source.
#define RCT_CUTOFF   21
#define APT_WINDOW   512
#define APT_CUTOFF   328

volatile uint8_t  lastBitValue     = 0;
volatile uint8_t  rctRunLength     = 0;
volatile uint8_t  aptReferenceBit  = 0;
volatile uint16_t aptMatchCount    = 0;
volatile uint16_t aptWindowCount   = 0;
volatile bool     healthTestFailed = false;

// Updates both health tests with one raw comparison bit. Called from
// geigerISR() for every bit, independent of whether entropyPool is full,
// so the source is monitored continuously rather than only while
// collecting. Sets healthTestFailed and never clears it - loop() halts
// the device on the next check, matching the existing boot-time KAT /
// wordlist halt behavior; a power cycle is required to resume.
void runHealthChecks(uint8_t bit) {
  // Repetition Count Test: too many identical bits in a row.
  if (bit == lastBitValue) {
    rctRunLength++;
    if (rctRunLength >= RCT_CUTOFF) healthTestFailed = true;
  } else {
    rctRunLength = 1;
    lastBitValue = bit;
  }

  // Adaptive Proportion Test: one value recurring too often within a
  // window of APT_WINDOW consecutive bits.
  if (aptWindowCount == 0) {
    aptReferenceBit = bit;
    aptMatchCount = 1;
  } else if (bit == aptReferenceBit) {
    aptMatchCount++;
    if (aptMatchCount >= APT_CUTOFF) healthTestFailed = true;
  }
  aptWindowCount++;
  if (aptWindowCount >= APT_WINDOW) aptWindowCount = 0; // start next window
}

void geigerISR() {
  totalPulseCount++;
  unsigned long now = micros();
  if (lastPulseMicros != 0) {
    unsigned long interval = now - lastPulseMicros;
    if (interval >= MIN_INTERVAL_US) {
      if (!haveFirstInterval) {
        firstInterval = interval;
        haveFirstInterval = true;
      } else {
        if (interval != firstInterval) {
          uint8_t bit = (interval > firstInterval) ? 1 : 0;
          runHealthChecks(bit);
          if (poolBitIndex < RAW_POOL_BITS) {
            uint16_t byteIdx   = poolBitIndex >> 3;
            uint8_t  bitOffset = poolBitIndex & 0x07;
            if (bit) entropyPool[byteIdx] |=  (1 << bitOffset);
            else     entropyPool[byteIdx] &= ~(1 << bitOffset);
            poolBitIndex++;
          }
        }
        // Whether or not a bit was emitted, both intervals of this pair
        // are now spent - start the next pair fresh rather than sliding
        // forward by one interval (that sliding is the overlap this
        // scheme exists to avoid).
        haveFirstInterval = false;
      }
      lastPulseMicros = now;
    }
  } else {
    lastPulseMicros = now;
  }
}

// ---------------- Buttons (polled, debounced) ----------------
Button backBtn = { BACK_PIN, HIGH, 0 };
Button fwdBtn  = { FWD_PIN,  HIGH, 0 };
#define DEBOUNCE_MS 30

bool buttonPressed(Button &b) {
  bool reading = digitalRead(b.pin);
  bool pressed = false;

  if (reading != b.lastState &&
      (millis() - b.lastChange) > DEBOUNCE_MS) {

    b.lastChange = millis();

    if (reading == LOW)
      pressed = true;

    b.lastState = reading;
  }

  return pressed;
}

// Blocks until both nav buttons are physically released (plus one
// debounce interval to let contact bounce settle) before the caller
// switches into STATE_SHOW_WORD. That state's page navigation is
// driven by buttonPressed()/fwdBtn/backBtn, which is separate debounce
// state from the raw digitalRead() combo-detection in readMenuAction().
// Without this wait, a button still held down at the exact moment of
// the state switch (very common right after a BACK+FWD combo press, or
// a held BACK press) looks to buttonPressed() like a brand-new press,
// silently skipping page 0 of the seed words.
void waitForNavButtonsReleased() {
  while (digitalRead(BACK_PIN) == LOW || digitalRead(FWD_PIN) == LOW) {
    delay(5);
  }
  delay(DEBOUNCE_MS);
}

// ---------------- Menu buttons ----------------
//
// BACK alone   = previous
// FWD alone    = next
// BACK + FWD   = select

#define COMBO_WINDOW_MS 150

enum MenuAction {
  MENU_NONE,
  MENU_BACK,
  MENU_FWD,
  MENU_SELECT
};

MenuAction readMenuAction();

bool menuComboPending = false;
bool menuComboHandled = false;
bool menuNavHandled = false;
bool menuFirstWasBack = false;
unsigned long menuFirstPressMs = 0;

MenuAction readMenuAction() {

  bool backDown = (digitalRead(BACK_PIN) == LOW);
  bool fwdDown  = (digitalRead(FWD_PIN)  == LOW);

  // Both buttons pressed = SELECT
  if (backDown && fwdDown) {
    if (!menuComboHandled) {
      menuComboHandled = true;
      return MENU_SELECT;
    }
    return MENU_NONE;
  }

  // Wait for both buttons to be released after SELECT
  if (menuComboHandled) {
    if (!backDown && !fwdDown) {
      menuComboHandled = false;
    }
    return MENU_NONE;
  }

  // A button is currently held down.
  // Don't generate another action until it is released.
  if (backDown || fwdDown) {
    if (!menuComboPending && !menuNavHandled) {
      menuComboPending = true;
      menuFirstWasBack = backDown;
      menuFirstPressMs = millis();
    }

    // Single button held long enough = one navigation action.
    if (menuComboPending && millis() - menuFirstPressMs >= COMBO_WINDOW_MS) {
      menuComboPending = false;
      menuNavHandled = true;
      return menuFirstWasBack ? MENU_BACK : MENU_FWD;
    }

    return MENU_NONE;
  }

  // Both released.
  menuComboPending = false;
  menuNavHandled = false;

  return MENU_NONE;
}

// ---------------- App state machine ----------------
enum AppState {
  STATE_COLLECTING,
  STATE_MENU_LENGTH,
  STATE_SHOW_WORD,
  STATE_DONE,
  STATE_WIPE_CONFIRM
};
AppState state = STATE_COLLECTING;

uint8_t  selectedLength  = 12;   // toggled between 12 / 24 in the menu
uint8_t  wordCount       = 0;
uint16_t wordIndices[24];

// Seed words are shown WORDS_PER_PAGE at a time (one page fills the whole
// screen) instead of one word per screen, so a 24-word seed takes 6
// button presses to read instead of 24.
#define WORDS_PER_PAGE 4
uint8_t currentPage = 0;

uint8_t totalPages() {
  return (wordCount + WORDS_PER_PAGE - 1) / WORDS_PER_PAGE;
}

// Looks up word `index` (0-2047) from the packed BIP39_WORDLIST_BLOB and
// copies it (plain ASCII, null-terminated) into `out`. The blob has no
// index -> offset table (that alone would cost 4KB of flash we don't
// have), so this walks null-terminated words from the start of the blob.
// Called at most WORDS_PER_PAGE times per screen draw and 24 times per
// generated phrase, so the O(index) scan cost is negligible.
void getWordAtIndex(uint16_t index, char* out, uint8_t outSize) {
  const char* p = BIP39_WORDLIST_BLOB;
  while (index > 0) {
    while (pgm_read_byte(p) != 0) p++;
    p++;
    index--;
  }
  uint8_t i = 0;
  uint8_t c;
  while ((c = pgm_read_byte(p)) != 0 && i < outSize - 1) {
    out[i++] = c;
    p++;
  }
  out[i] = '\0';
}
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
void loop() {
  switch (state) {

    case STATE_COLLECTING:
      updateCollectingScreen();
      // Checked here rather than inside the ISR (which only sets the
      // flag) so a failing source halts before its output ever reaches
      // generatePhrase() - see runHealthChecks().
      if (healthTestFailed) {
        drawStatusLine("HEALTH TEST FAIL");
        while (true) { delay(1000); } // halt - power cycle to retry
      }
      if (poolBitIndex >= RAW_POOL_BITS) {
        state = STATE_MENU_LENGTH;
        drawMenuScreen();
      }
      break;

    case STATE_MENU_LENGTH: {
      MenuAction action = readMenuAction();

      if (action == MENU_BACK) {
        selectedLength = (selectedLength == 12) ? 24 : 12;
        drawMenuScreen();

      } else if (action == MENU_FWD) {
        selectedLength = (selectedLength == 12) ? 24 : 12;
        drawMenuScreen();

      } else if (action == MENU_SELECT) {
        waitForNavButtonsReleased();
        generatePhrase();
        state = STATE_SHOW_WORD;
        currentPage = 0;
        drawWordScreen();
      }

      break;
    }

    case STATE_SHOW_WORD:
      if (buttonPressed(fwdBtn)) {
        if (currentPage < totalPages() - 1) {
          currentPage++;
          drawWordScreen();
        } else {
          state = STATE_DONE;
          drawDoneScreen();
        }
      }
      if (buttonPressed(backBtn)) {
        if (currentPage > 0) {
          currentPage--;
          drawWordScreen();
        }
      }
      break;

    case STATE_DONE: {
      MenuAction action = readMenuAction();

      if (action == MENU_BACK) {
        waitForNavButtonsReleased();
        state = STATE_SHOW_WORD;
        currentPage = totalPages() - 1;
        drawWordScreen();

      } else if (action == MENU_SELECT) {
        state = STATE_WIPE_CONFIRM;
        drawWipeConfirmScreen();
      }

      break;
    }

    case STATE_WIPE_CONFIRM: {
      MenuAction action = readMenuAction();

      if (action == MENU_SELECT) {
        wipeSeed();
        state = STATE_COLLECTING;
        lcd.clear();
        lcd.drawString(0, 0, "ENTROPY32");
        lcd.drawString(0, 2, "COLLECTING...");

      } else if (action == MENU_BACK || action == MENU_FWD) {
        // Any single-button press cancels back to the done screen
        // rather than the wipe.
        state = STATE_DONE;
        drawDoneScreen();
      }

      break;
    }
  }
}

// ---------------- Screens ----------------
unsigned long lastCollectDraw = 0;

// Rolls the pulse count into a 60-second sliding window, called once per
// second. During the first 60s after boot the window isn't full yet, so
// we scale the observed rate up proportionally rather than under-report
// (e.g. 5 counts in the first 5 seconds reads as ~60 CPM, not ~5 CPM).
void updateCPMWindow() {
  if (millis() - cpmLastTickMs < 1000) return;
  cpmLastTickMs += 1000;

  noInterrupts();
  uint32_t currentTotal = totalPulseCount;
  interrupts();

  uint32_t deltaThisSecond = currentTotal - cpmLastPulseSnapshot;
  cpmLastPulseSnapshot = currentTotal;

  cpmRollingSum -= cpmSecondBuckets[cpmBucketIdx];
  cpmSecondBuckets[cpmBucketIdx] = (deltaThisSecond > 65535UL) ? 65535 : (uint16_t)deltaThisSecond;
  cpmRollingSum += cpmSecondBuckets[cpmBucketIdx];

  cpmBucketIdx = (cpmBucketIdx + 1) % CPM_WINDOW_SECONDS;

  if (cpmSecondsElapsed < CPM_WINDOW_SECONDS) cpmSecondsElapsed++;
}

uint32_t getCurrentCPM() {
  if (cpmSecondsElapsed == 0) return 0;
  if (cpmSecondsElapsed < CPM_WINDOW_SECONDS) {
    return (cpmRollingSum * CPM_WINDOW_SECONDS) / cpmSecondsElapsed; // extrapolate partial window
  }
  return cpmRollingSum; // full 60s of data = directly CPM
}

// Formats CPM with K/M/G suffixes so the value can never overrun a fixed-
// width field, regardless of count rate. Max output is 6 chars + null
// (e.g. "12.3K", "4.2G") — uint32_t itself tops out around 4.29 billion,
// so the G tier alone covers the entire representable range.
void formatCPM(uint32_t cpm, char* out) {
  const char* suffix = "";
  uint32_t divisor = 1;
  if (cpm >= 1000000000UL)      { suffix = "G"; divisor = 1000000000UL; }
  else if (cpm >= 1000000UL)    { suffix = "M"; divisor = 1000000UL; }
  else if (cpm >= 1000UL)       { suffix = "K"; divisor = 1000UL; }

  if (divisor == 1) {
    sprintf(out, "%lu", cpm); // 0-999, no suffix, max 3 chars
    return;
  }

  uint32_t whole = cpm / divisor;
  if (whole >= 100) {
    // 3-digit whole + suffix = 4 chars; adding a decimal here would hit 6, so we drop it.
    sprintf(out, "%lu%s", whole, suffix);
  } else {
    // Up to "99.9K" = 5 chars, exactly fits the field.
    uint32_t frac = ((cpm % divisor) * 10) / divisor;
    sprintf(out, "%lu.%lu%s", whole, frac, suffix);
  }
}

// Renders an ASCII progress bar exactly OLED_COLS wide, e.g.
// "[#######-------]", by filling PROGRESS_BAR_WIDTH segments in
// proportion to current/maxVal. `out` must be at least OLED_COLS+1 bytes.
#define PROGRESS_BAR_WIDTH (OLED_COLS - 2) // 2 cols spent on the brackets
void buildProgressBar(uint16_t current, uint16_t maxVal, char* out) {
  uint8_t filled = (uint8_t)(((uint32_t)current * PROGRESS_BAR_WIDTH) / maxVal);
  if (filled > PROGRESS_BAR_WIDTH) filled = PROGRESS_BAR_WIDTH;

  out[0] = '[';
  uint8_t i;
  for (i = 0; i < filled; i++) out[1 + i] = '#';
  for (; i < PROGRESS_BAR_WIDTH; i++) out[1 + i] = '-';
  out[1 + PROGRESS_BAR_WIDTH] = ']';
  out[2 + PROGRESS_BAR_WIDTH] = '\0';
}

// Formats a duration for the "time left" estimate. Caps at "99H+" rather
// than letting an absurdly weak/absent source (near-zero CPM) overflow
// the field with a multi-day estimate.
void formatDuration(uint32_t totalSeconds, char* out, size_t outSize) {
  if (totalSeconds >= 359999UL) { // >= 99h59m59s
    snprintf(out, outSize, "99H+");
    return;
  }
  uint32_t h = totalSeconds / 3600;
  uint32_t m = (totalSeconds % 3600) / 60;
  uint32_t s = totalSeconds % 60;
  if (h > 0)      snprintf(out, outSize, "%luH%02luM", h, m);
  else if (m > 0) snprintf(out, outSize, "%luM%02luS", m, s);
  else            snprintf(out, outSize, "%luS", s);
}

void updateCollectingScreen() {
  updateCPMWindow(); // ticks once per second, independent of the 250ms display throttle below

  if (millis() - lastCollectDraw > 250) {
    lastCollectDraw = millis();

    noInterrupts();
    uint16_t idx = poolBitIndex;
    uint8_t byteSnapshot = (idx > 0) ? entropyPool[(idx - 1) >> 3] : 0;
    interrupts();

    char lastBitChar = '-';
    if (idx > 0) {
      lastBitChar = ((byteSnapshot >> ((idx - 1) & 0x07)) & 1) ? '1' : '0';
    }

    uint32_t cpm = getCurrentCPM();
    char cpmStr[6];
    formatCPM(cpm, cpmStr);

    char lineBuf[OLED_COLS + 1];
    snprintf(lineBuf, sizeof(lineBuf), "LB: %c CPM: %-5.5s", lastBitChar, cpmStr);
    lcd.drawString(0, 0, lineBuf);

    buildProgressBar(idx, RAW_POOL_BITS, lineBuf);
    lcd.drawString(0, 1, lineBuf);

    snprintf(lineBuf, sizeof(lineBuf), "BITS: %u/%u   ", idx, RAW_POOL_BITS);
    lcd.drawString(0, 2, lineBuf);

    // ETA assumes accepted-bit rate roughly tracks half the pulse rate
    // (CPM), since geigerISR() now spends two intervals (~two pulses) per
    // output bit under non-overlapping pairing - see the "Entropy method"
    // note at the top of this file. Shown as "--" until the CPM window
    // has any data yet, or if CPM is genuinely zero (no pulses -> no
    // progress possible).
    char etaLine[OLED_COLS + 1];
    if (cpm == 0) {
      snprintf(etaLine, sizeof(etaLine), "EST: %-10s", "--");
    } else {
      uint16_t remainingBits = RAW_POOL_BITS - idx;
      uint32_t etaSeconds = ((uint32_t)remainingBits * 2UL * 60UL) / cpm;
      char durBuf[12];
      formatDuration(etaSeconds, durBuf, sizeof(durBuf));
      snprintf(etaLine, sizeof(etaLine), "EST: %-10s", durBuf);
    }
    lcd.drawString(0, 3, etaLine);
  }
}

void drawMenuScreen() {
  lcd.clear();
  lcd.drawString(0, 0, "SEED LENGTH:");
  char lineBuf[OLED_COLS + 1];
  snprintf(lineBuf, sizeof(lineBuf), "%u", selectedLength);
  lcd.drawString(0, 2, lineBuf);
}
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

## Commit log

2026-09-11 Update firmware and increase green LED resistor to 2.2k from 1k.
    [geiger_entropy.kicad_sch]
2026-09-12 Update PCB to include M2.5 mounting holes
    [bom.csv, designators.csv, geiger_entropy.kicad_pcb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]
2026-09-12 Add button debounce guard and capitalise seed phrase words for ease of copy
2026-09-12 Add 3d printed case
    [Basic-case.3mf]
2026-09-12 Document case in readme and add image of it
2026-09-12 Remove PCB mounting holes, satisfied with existing enclosure design
    [geiger_entropy.kicad_pcb]
2026-09-12 Update the PCB image
2026-09-12 Update basic case image
2026-09-12 Update PCB
    [geiger_entropy.kicad_pcb]
2026-09-12 Upgrade basic case
    [Basic-case.3mf]
2026-09-12 Update fabrication outputs
    [designators.csv, positions.csv]
2026-09-13 Update PCB with more vias and a missing ISP program header annotation
    [geiger_entropy.kicad_pcb]
2026-09-14 Fix overlapping inter-arrival-time comparisons in entropy source
    Adjacent Geiger inter-arrival times were each compared to the one
    before them (T2 vs T1, then T3 vs T2, ...), reusing every interval in
    two consecutive comparisons and correlating adjacent output bits even
    when the underlying intervals are IID. Switch to non-overlapping
    interval pairs (T1,T2 -> bit, T3,T4 -> bit, ...) so each interval
    feeds exactly one comparison, and update the collection-screen ETA
    math for the resulting ~halved raw bit rate.
    Credit to Cosmographer / BHRIGU (https://www.bhrigu.io) for
    identifying the issue, acknowledged in the README.
    Claude-Session: h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
    [Basic-case.3mf]
2026-09-14 Add SP 800-90B runtime health checks to entropy source
    Run the two NIST SP 800-90B minimal continuous health tests -
    Repetition Count Test and Adaptive Proportion Test - on every raw
    comparison bit before it's added to the entropy pool, halting the
    device rather than generating a seed if the Geiger source looks
    stuck or degraded. Cutoffs are derived assuming a conservative
    per-bit min-entropy of 1 and a false-positive rate of 2^-20.
    Confirmed the build still fits: 30234/30720 bytes flash (98%),
    1061/2048 bytes RAM (51%).
    Claude-Session: https://claude.ai/code/session_014XjwyCu7LpWJwwHrLUnVcn
    [entropy32_plus.ino]
2026-09-14 Uppercase all OLED display text for legibility
    The 0.91" panel's small font makes mixed-case text hard to read at a
    glance; seed words were already uppercased for the same reason, so
    extend it to every status line, label, and formatted field.
    Claude-Session: https://claude.ai/code/session_01BC94QZ5ejNFUv2ATLjUT2y
2026-09-15 Add seed generation time table and fix stale README references
    Adds a CPM-to-time table for filling the 512-bit entropy pool, derived
    from the same math the firmware uses for its on-device ETA. Also fixes
    README references to the old entropy32.ino filename and wordlist/logo
    tool paths that had moved to tools/.
    Claude-Session: https://claude.ai/code/session_0138MCfJy2VmpY1QeivKELWG
2026-09-15 Track production zip file
2026-09-16 Update schematics
    [geiger_entropy.kicad_sch]
2026-09-16 Add user manual with device photos and ICSP flashing instructions
    Adds MANUAL.md covering day-to-day operation for people who already have
    an assembled/flashed device, and documents burning the bootloader and
    flashing a bare ATmega328P via ICSP in the README's build section.
2026-09-18 Adjust enclosure tolerances and alter the retention clip shape
    [Basic-case.3mf]
2026-09-23 Add pilot SP 800-90B entropy results to README
    Summarise the 10-hour Entropy32 Recorder capture and its ea_non_iid
    results in the Validation section, with the sample-size caveats and a
    link to the published evidence directory. Trim the README and the
    firmware header comment to keep them focused on the design itself.
2026-11-03 Add full-length 2,000,000-edge SP 800-90B results to README
    Reference the 2026-10-03a evidence package from Entropy32 Recorder
    (H ~= 0.828 bits per comparison bit, compression estimator), state that
    it is one sample short of 1,000,000 and is labelled a pilot by
    verify_evidence.py, and condense the earlier 10,000-edge pilot.
